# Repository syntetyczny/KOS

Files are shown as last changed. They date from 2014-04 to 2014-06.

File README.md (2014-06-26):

KOS
===

Another RepRap controller based on teensylu/printrboard and more. 

Project and all files attached are licensed by Creative Commons license CC BY-NC-ND 3.0 . If you want to comercially use project contact the author:
Paweł Janusz Dobrowolski
email: pawel.j.dobrowolski@gmail.com
company email: pjd@pjd-automatyka.pl

legal links:
http://creativecommons.org/licenses/by-nc-nd/3.0/
http://creativecommons.org/licenses/by-nc-nd/3.0/pl/legalcode
http://creativecommons.org/licenses/by-nc-nd/3.0/pl/

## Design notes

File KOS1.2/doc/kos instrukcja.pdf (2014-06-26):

## Instrukcja obsługi do kontrolera 4 osiowego dla drukarek 3D typu RepRap

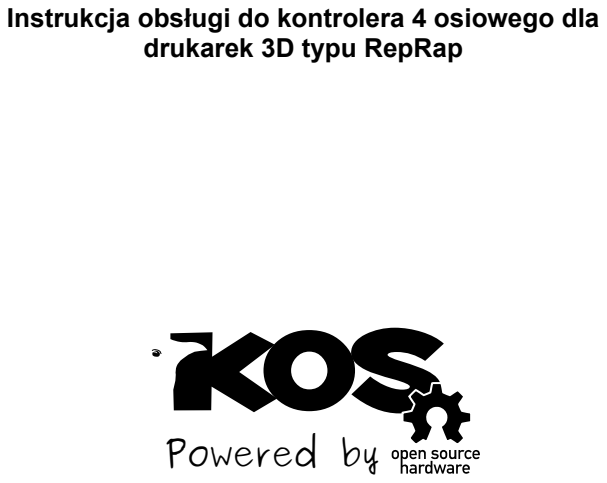
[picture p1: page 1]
Powered by

## Spis treści

## 1 Wstęp

KOS 1.2 jest elektroniką stworzoną z uwzględnieniem doświadczenia zebranego na budowaniu drukarek 3D Prusa. Wyposażono ją w złącza śrubowe, szeroko stosowane w elektronice przemysłowej, które eliminują błędy montażowe takie jak źle zaciśnięte wtyczki, czy też zbyt mała powierzchnia styku. Sterownik KOS 1.2 został dodatkowo wyposażony w czytelne złącza pod ekran LCD, czytnik karty SD oraz enkoder z guzikiem 47. Dzięki temu możemy bez problemu umieścić panel sterujący drukarką tam, gdzie nam się podoba. Na płytce umieszczono dodatkowo potencjometr do regulacji kontrastu wyświetlacza oraz rezystor regulujący intensywność podświetlenia, co zmniejsza poziom skomplikowania przy montażu dodatkowych peryferiów.

Jedną niezaprzeczalną zaletą elektroniki KOS jest możliwość stosowania naraz 3 różnych napięć. Oznacza to, że możemy silniki zasilić napięciem Vmot od 12-30V, grzałek napięciem Vhot od 12-30V i logiki napięciem P1 = 12V bądź zasilić logikę z portu USB 5. Taka ilość możliwości nie każdemu jest potrzebna, więc wprowadzono dodatkowo zworki pozwalające na przełączanie zasilania dla uproszczenia instalacji.

Elektronika KOS 1.2 jest wyposażona w procesor AT90USB1286/7 , który jest szeroko stosowanym kontrolerem 8 bitowym w drukarkach 3D typu RepRap. Jego zaletą jest natywna obsługa portu USB, pozwalająca na szybką wymianę danych i bezproblemową komunikację pomiędzy komputerem, a drukarką. Procesor ten jest stosowany w elektronikach takich jak Teensylu, Printrboard, SAV MKI, Sunbeam, Uniqueone i wiele innych. Jest to najpopularniejszy procesor z rodziny AVR w świecie druku 3D.

## 2 Schemat podłączeniowy

Poniżej przedstawiono schemat podłączenia podstawowych peryferiów drukarki 3D takich jak: grzałka, podgrzewany stół, silniki itd. Trzeba pamiętać o dobraniu odpowiednich kabli o odpowiednim przekroju.

- Silniki: 0.35mm²
- Grzałki: 1.5mm²
- Krańcówki, termistory, wyłącznik bezpieczeństwa E-Stop: 0.35mm²
- Zasilacze: 1.5mm²

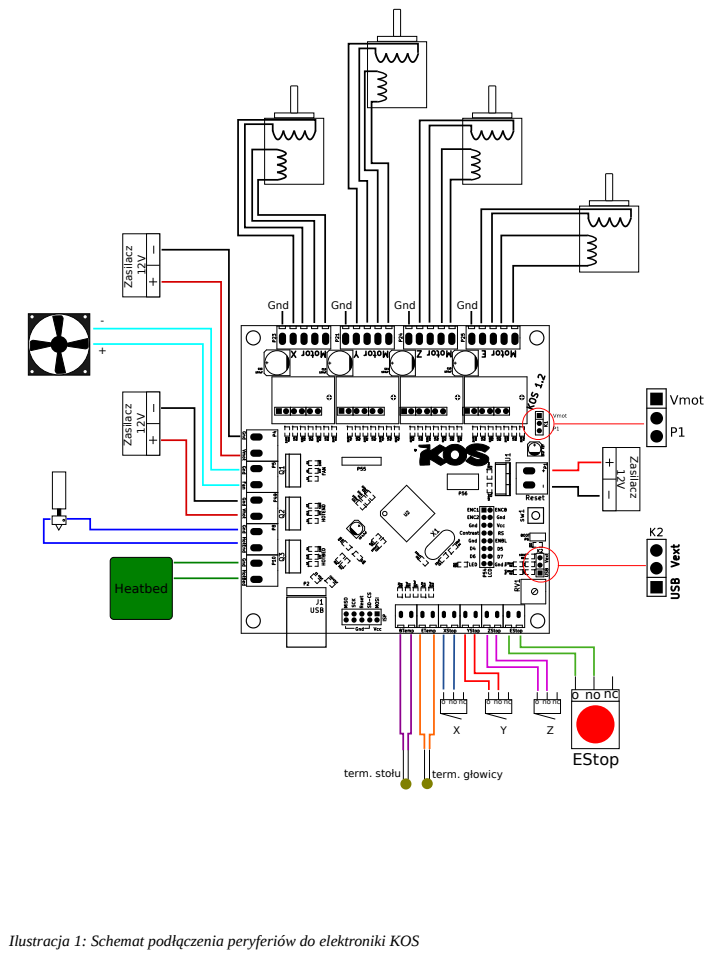
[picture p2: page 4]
Heatbed; term. stołu; term. głowicy; EStop; Zasilacz; Gnd

Ilustracja 1: Schemat podłączenia peryferiów do elektroniki KOS

### 2.1 Opis zworek odpowiadających za zasilanie

W elektronice KOS występuje możliwość podpięcia różnych rodzajów zasilania w zależności od aplikacji. W związku z tym, umieszczono 2 listwy kołkowe, które odpowiadają za przełączenie zasilania elektroniki z zasilania z portu USB na zasilanie ze złącza P1 – zasilania do 12V wyłącznie dla celów procesora i logiki, bądź z łącza Vmot – gdy zasilamy silniki napięciem 12V, możemy je wykorzystać również do zasilania procesora i logiki przełączając odpowiednią zworkę. W poniższej tabeli zaprezentowano możliwe konfiguracje.

lp. | Zworka | Opis
1 | | Brak wybranego zasilania dla elektroniki
2 | | Zasilanie elektroniki z portu USB bez względu na wybór źródła napięcia na zworce K1
3 | | Zasilanie ze źródła zewnętrznego Vmot wybranego na zworce K1
4 | | Zasilanie ze źródła zewnętrznego P1 wybranego na zworce K1

### 2.2 Opis zworek odpowiedzialnych za wybór kroków

Do każdego silnika krokowego są przypisane zworki odpowiadające za podział kroków na sterownikach silników krokowych opartych o układ scalony firmy Allegro A4988. Poniżej opisano możliwe konfiguracje.

lp. | Zworki | Opis
1 | | Tryb pełno krokowy (1)
2 | | Tryb półkrokowy (½)
3 | | Tryb ¼ kroku (¼)
4 | | Tryb 1/8 kroku (1/8)
5 | | Tryb 1/16 kroku (1/16)

## 3 Sterowniki i oprogramowanie dla systemu Windows

Elektronika KOS jest zaprojektowana tak aby była kompatybilna wstecznie z elektroniką teensylu, więc aby poprawnie działała z komputerem, wymagana jest instalacja sterowników. Jeżeli elektronika jest dostarczona z już wgranym programem Marlin, wystarczy zainstalować sterowniki ze strony projektu teensy 1.

W przeciwnym przypadku musimy stworzyć nową kompilację Marlin'a postępując zgodnie z instrukcją w dziale „Kompilacja Marlina” 5. Jednakże, zanim przejdziemy do tego, nasza elektronika wymaga bibliotek od oprogramowania Arduino, Teensyduino, oraz FLIP, które wcześniej musimy zainstalować:

- arduino ze strony autorów 2
- pakietu teensyduino 3
- programu FLIP for Windows 4

### 3.1 Instalacja pakietu Arduino

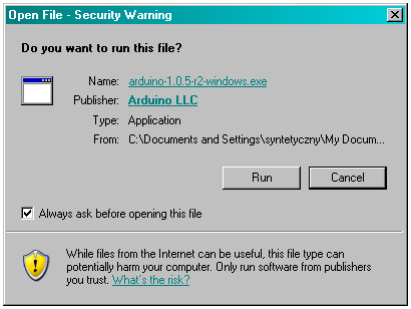
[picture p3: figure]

Ilustracja 2: Zezwolenie na uruchomienie pliku z niewiadomego źródła

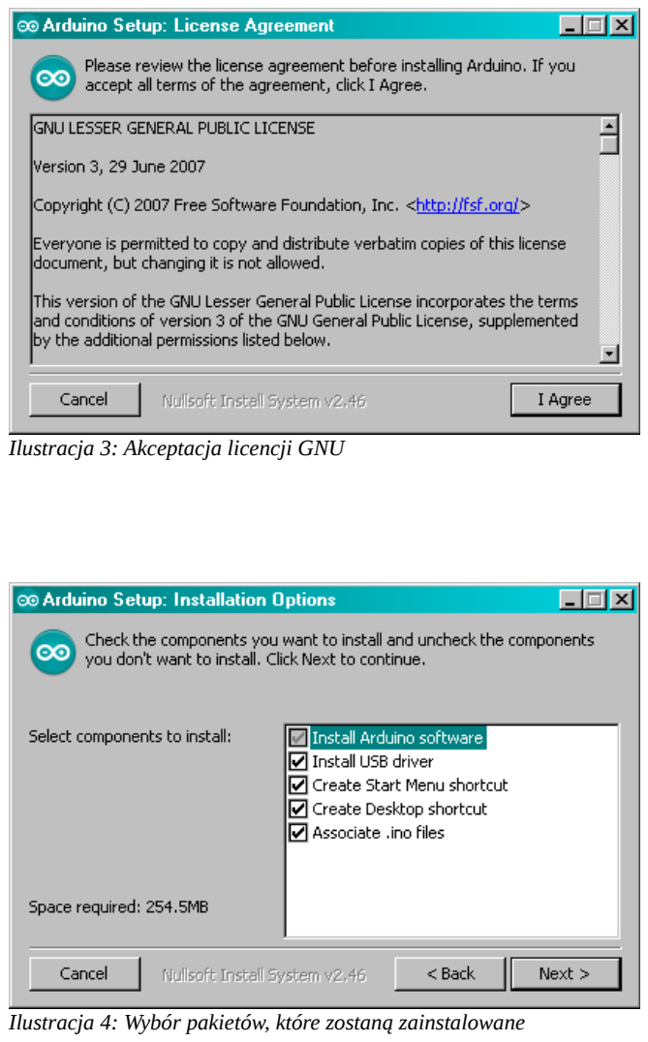
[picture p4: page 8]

Ilustracja 3: Akceptacja licencji GNU

Ilustracja 4: Wybór pakietów, które zostaną zainstalowane

Ilustracja 5: Wybór lokalizacji, gdzie zostanie zainstalowane Arduino

Ilustracja 6: Ostrzeżenie systemu Windows przed instalowaniem niezweryfikowanego oprogramowania

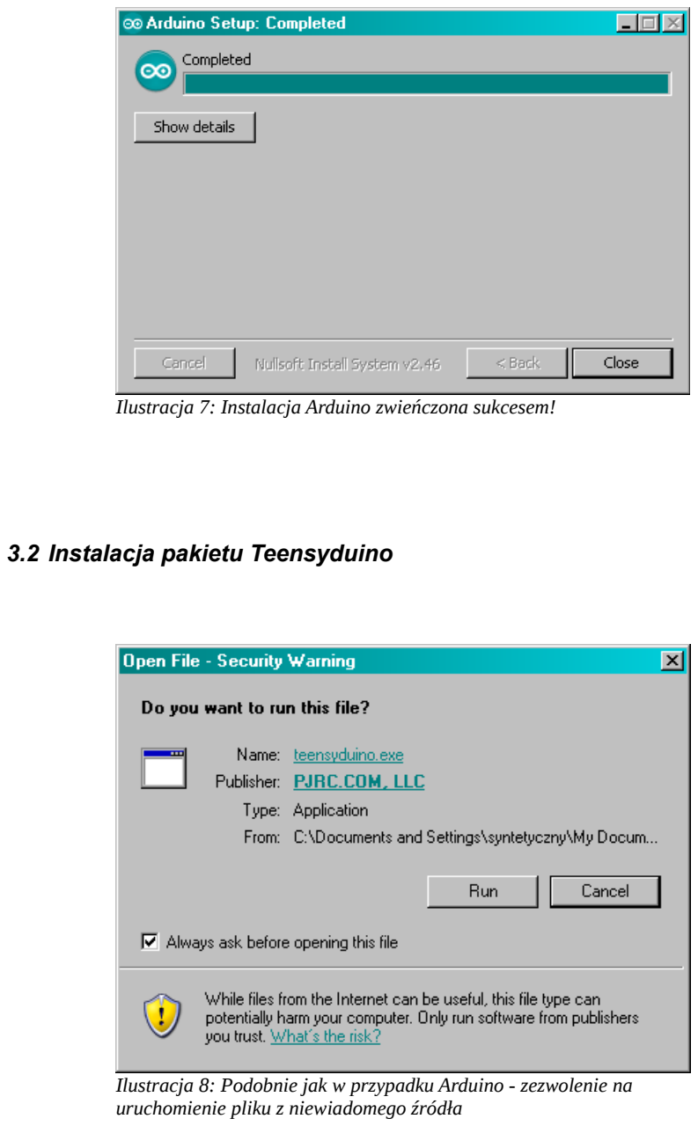
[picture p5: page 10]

### 3.2 Instalacja pakietu Teensyduino

Ilustracja 8: Podobnie jak w przypadku Arduino - zezwolenie na uruchomienie pliku z niewiadomego źródła

Ilustracja 7: Instalacja Arduino zwieńczona sukcesem!

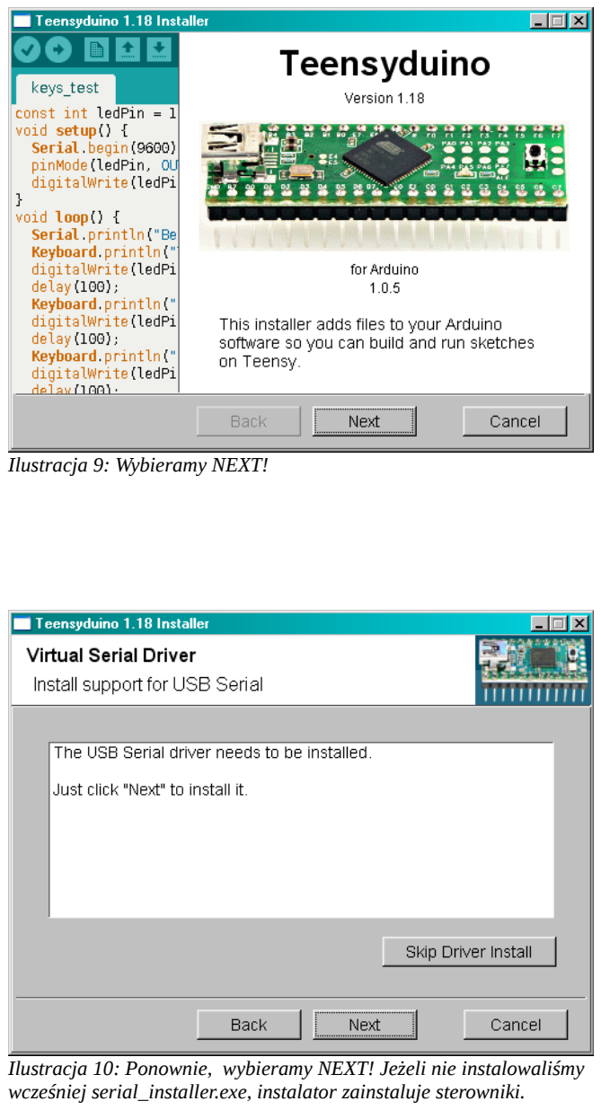
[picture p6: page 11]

Ilustracja 9: Wybieramy NEXT!

Ilustracja 10: Ponownie, wybieramy NEXT! Jeżeli nie instalowaliśmy wcześniej serial_installer.exe, instalator zainstaluje sterowniki.

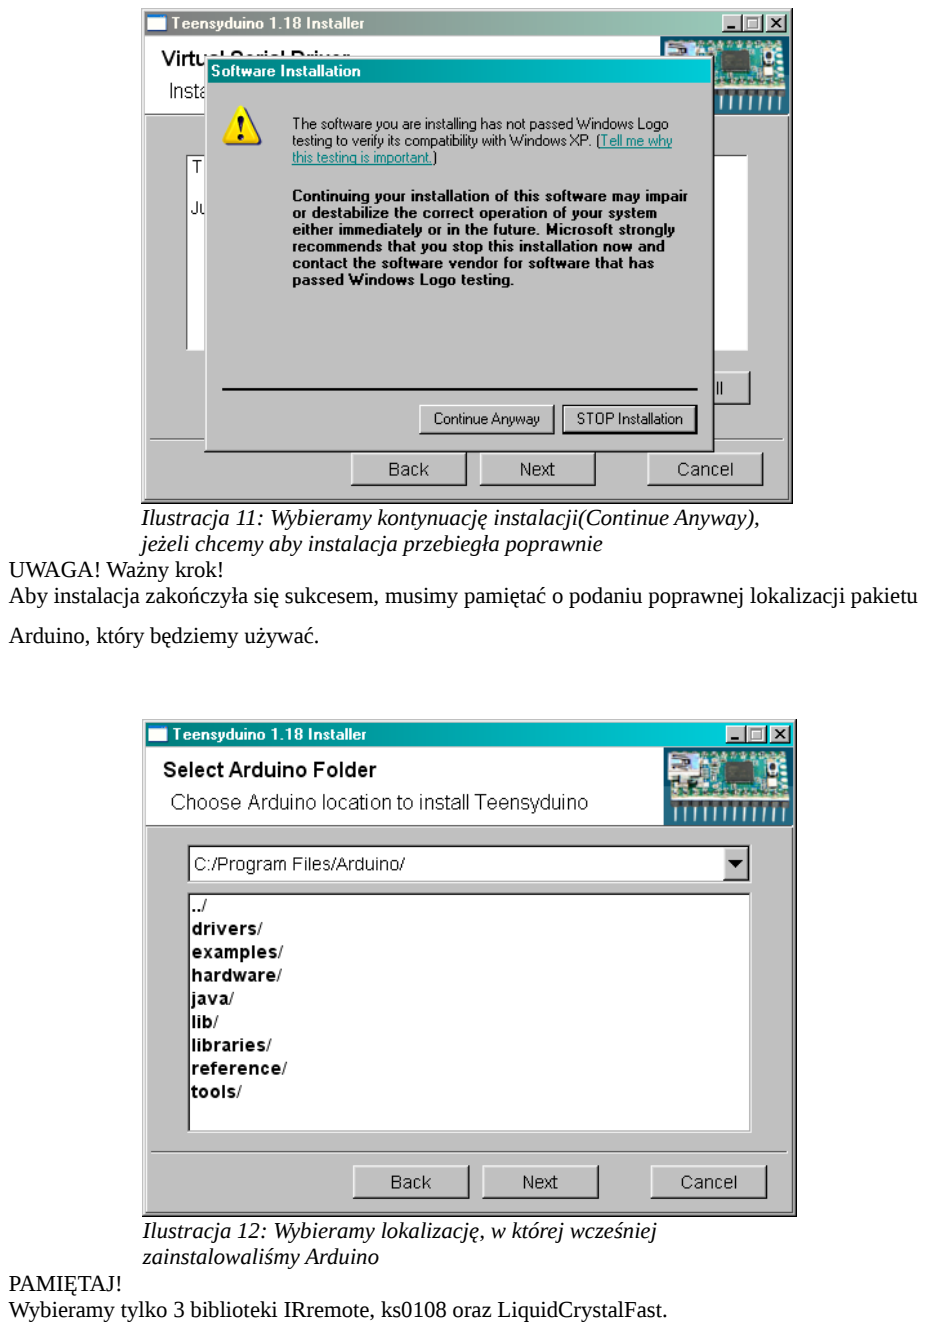
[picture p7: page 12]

UWAGA! Ważny krok!
Aby instalacja zakończyła się sukcesem, musimy pamiętać o podaniu poprawnej lokalizacji pakietu Arduino, który będziemy używać.

PAMIĘTAJ!
Wybieramy tylko 3 biblioteki IRremote, ks0108 oraz LiquidCrystalFast.

Ilustracja 11: Wybieramy kontynuację instalacji(Continue Anyway), jeżeli chcemy aby instalacja przebiegła poprawnie

Ilustracja 12: Wybieramy lokalizację, w której wcześniej zainstalowaliśmy Arduino

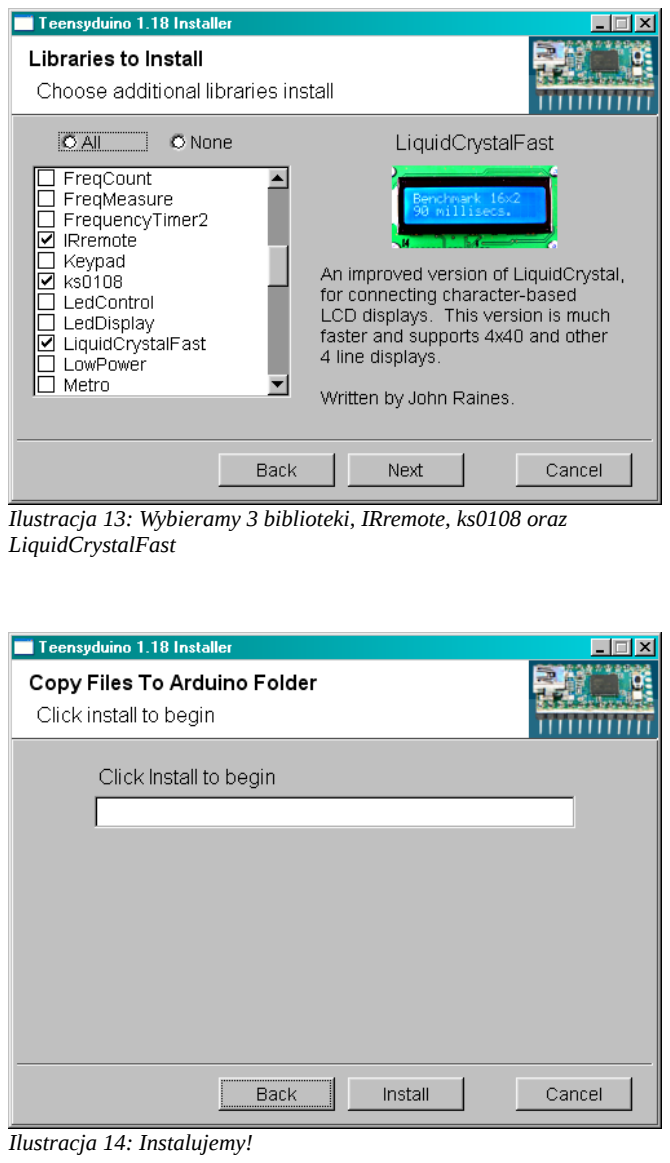
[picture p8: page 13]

Ilustracja 13: Wybieramy 3 biblioteki, IRremote, ks0108 oraz LiquidCrystalFast

Ilustracja 14: Instalujemy!

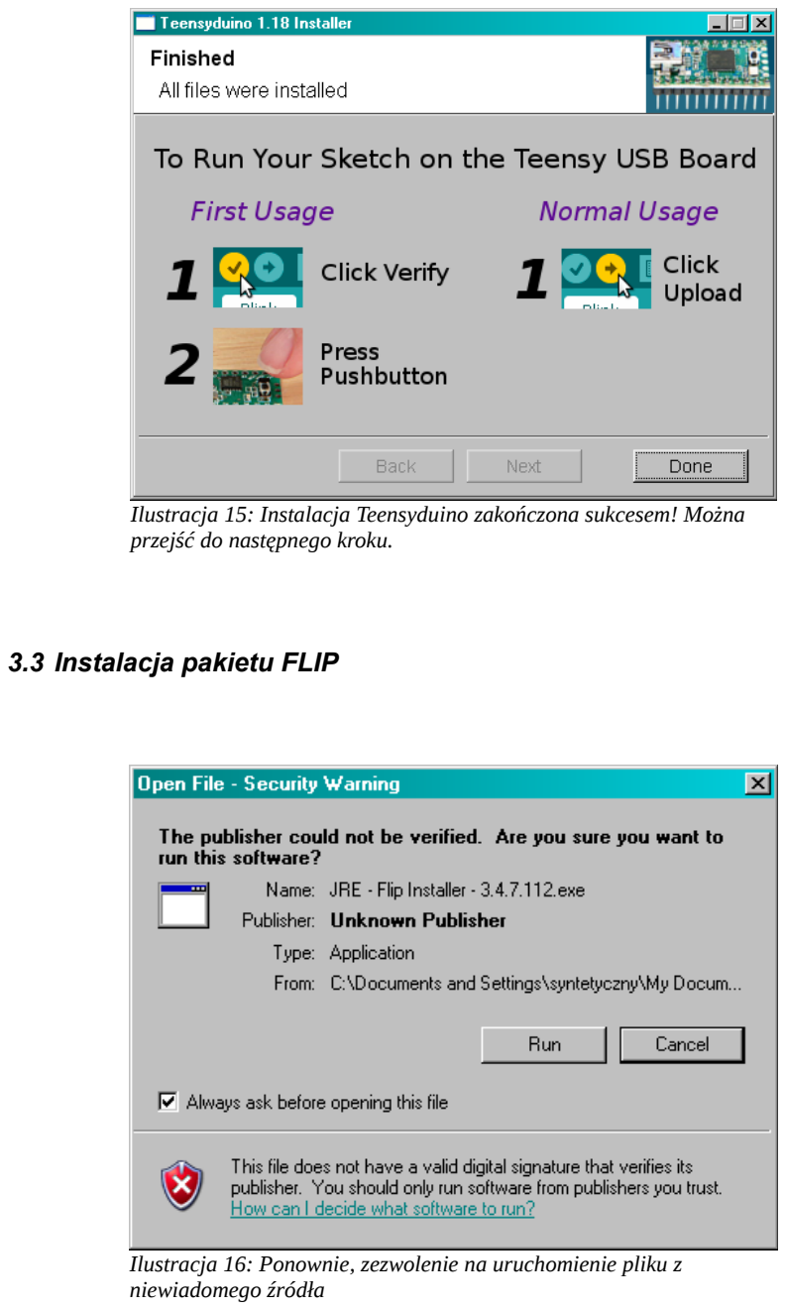
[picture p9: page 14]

### 3.3 Instalacja pakietu FLIP

Ilustracja 15: Instalacja Teensyduino zakończona sukcesem! Można przejść do następnego kroku.

Ilustracja 16: Ponownie, zezwolenie na uruchomienie pliku z niewiadomego źródła

Ilustracja 17: W przypadku braku zainstalowanego pakietu Javy musimy ją doinstalować

Ilustracja 18: Wybieramy standardową instalację i akceptujemy. Możemy przejść do następnego kroku.

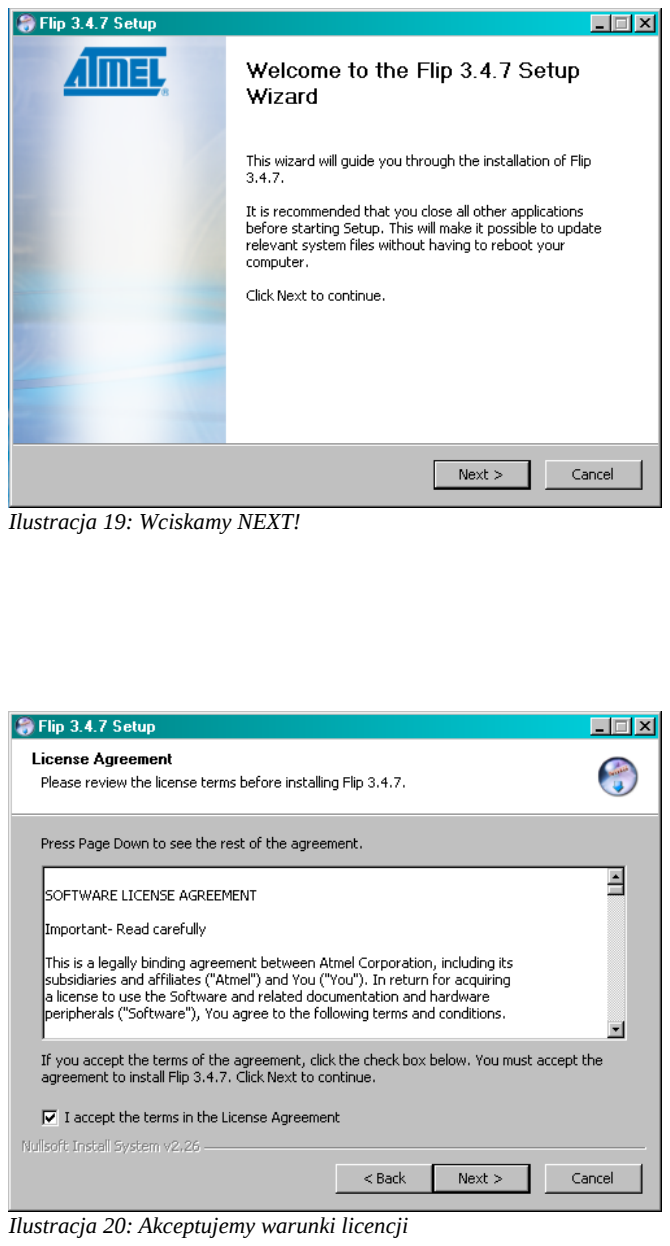
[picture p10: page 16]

Ilustracja 19: Wciskamy NEXT!

Ilustracja 20: Akceptujemy warunki licencji

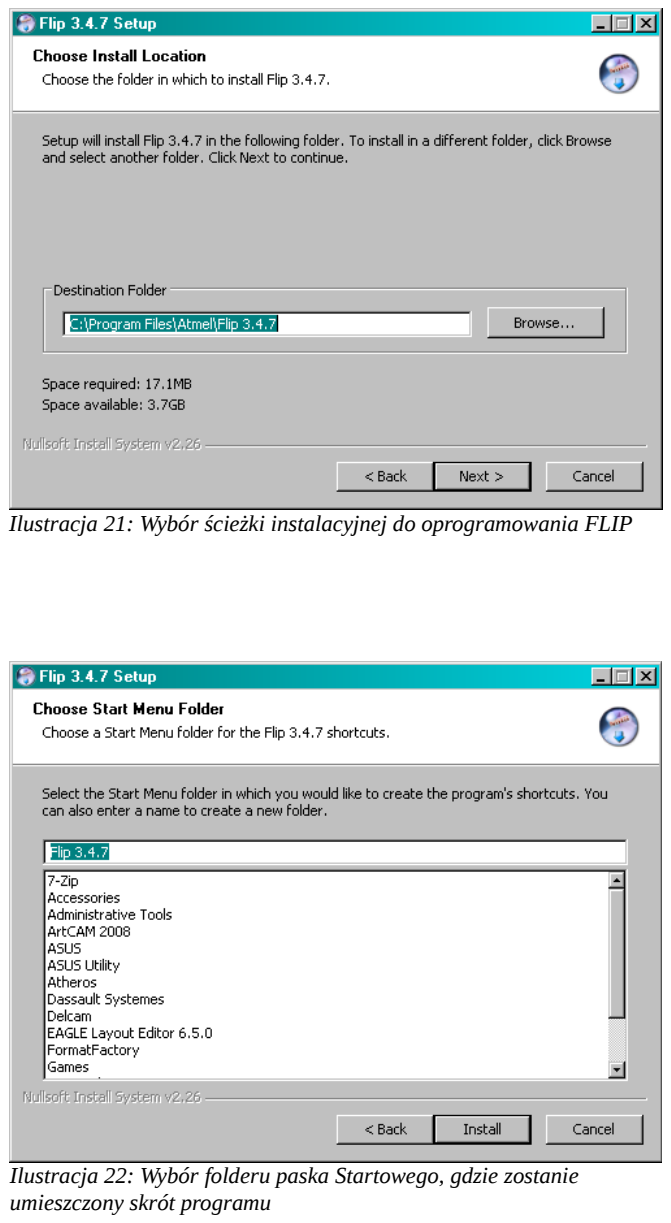
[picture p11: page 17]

Ilustracja 21: Wybór ścieżki instalacyjnej do oprogramowania FLIP

Ilustracja 22: Wybór folderu paska Startowego, gdzie zostanie umieszczony skrót programu

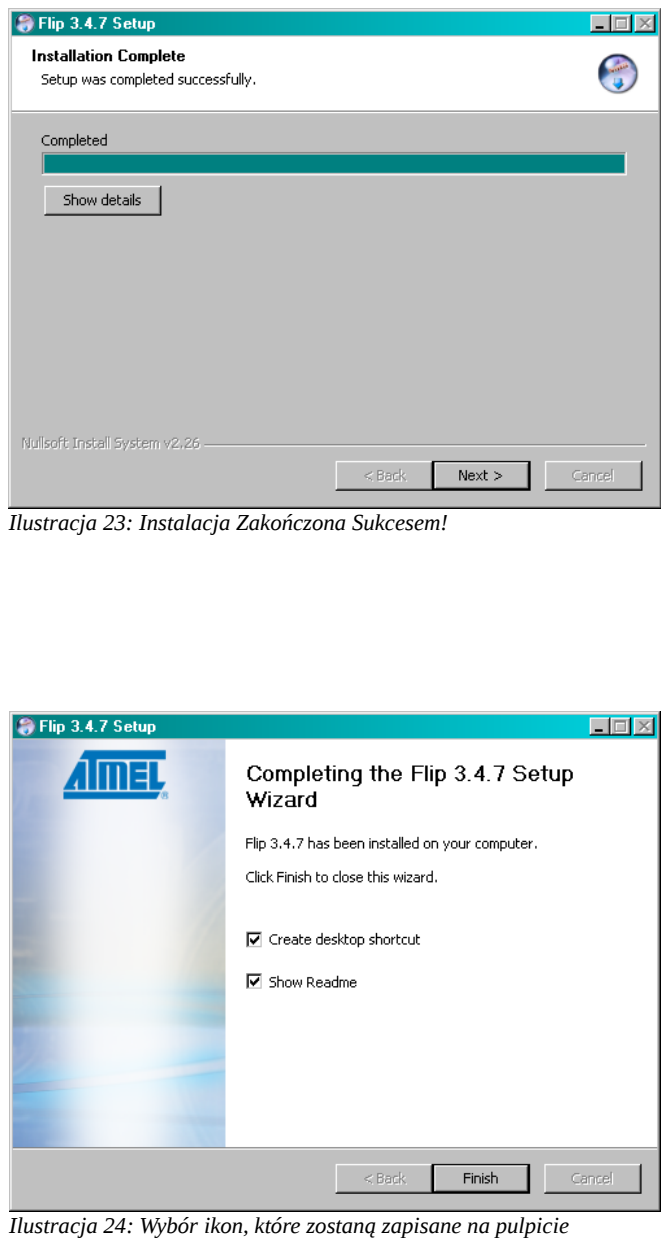
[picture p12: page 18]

Ilustracja 23: Instalacja Zakończona Sukcesem!

Ilustracja 24: Wybór ikon, które zostaną zapisane na pulpicie

## 4 Sterowniki i oprogramowanie dla systemów Linux Ubuntu

Tak samo jak w przypadku sterowników dla systemu Windows, zaczynamy od ściągnięcia pakietu Arduino ze strony producenta 2 . I rozpakowaniu w dowolnej lokalizacji. Następnie przy pomocy terminala, doinstalowujemy potrzebne pakiety:

sudo apt-get install gcc-avr avr-libc

sudo apt-get install openjdk-6-jre

Następnie, dodajemy prawa wykonywania dla programu Arduino. W tym celu musimy przejść do folderu z rozpakowanym Arduino i przy użyciu prawego klawisza myszki wejść we Właściwości i w zakładce Uprawnienia zaznaczyć Zezwolenie na wykonanie pliku jako programu .

Następnie, pobieramy teensyduino ze strony autorów w wersji zgodnej z naszym systemem(32 / 64 bity) i zapisujemy w dogodnej dla nas lokalizacji. Aby móc uruchomić program, otwieramy terminal (ctrl + alt + t) i przechodzimy do miejsca, gdzie znajduje się plik:

cd /home/nazwa_użytkownika/Lokalizacja/Pliku

Następnie za pomocą komendy chmod nadajemy prawa wykonywania pliku teensyduino.32bit

chmod 755 teensyduino.32bit

A następnie uruchamiamy instalator przy pomocy komendy ./teensyduino.32bit i postępujemy zgodnie z poleceniami instalatora:

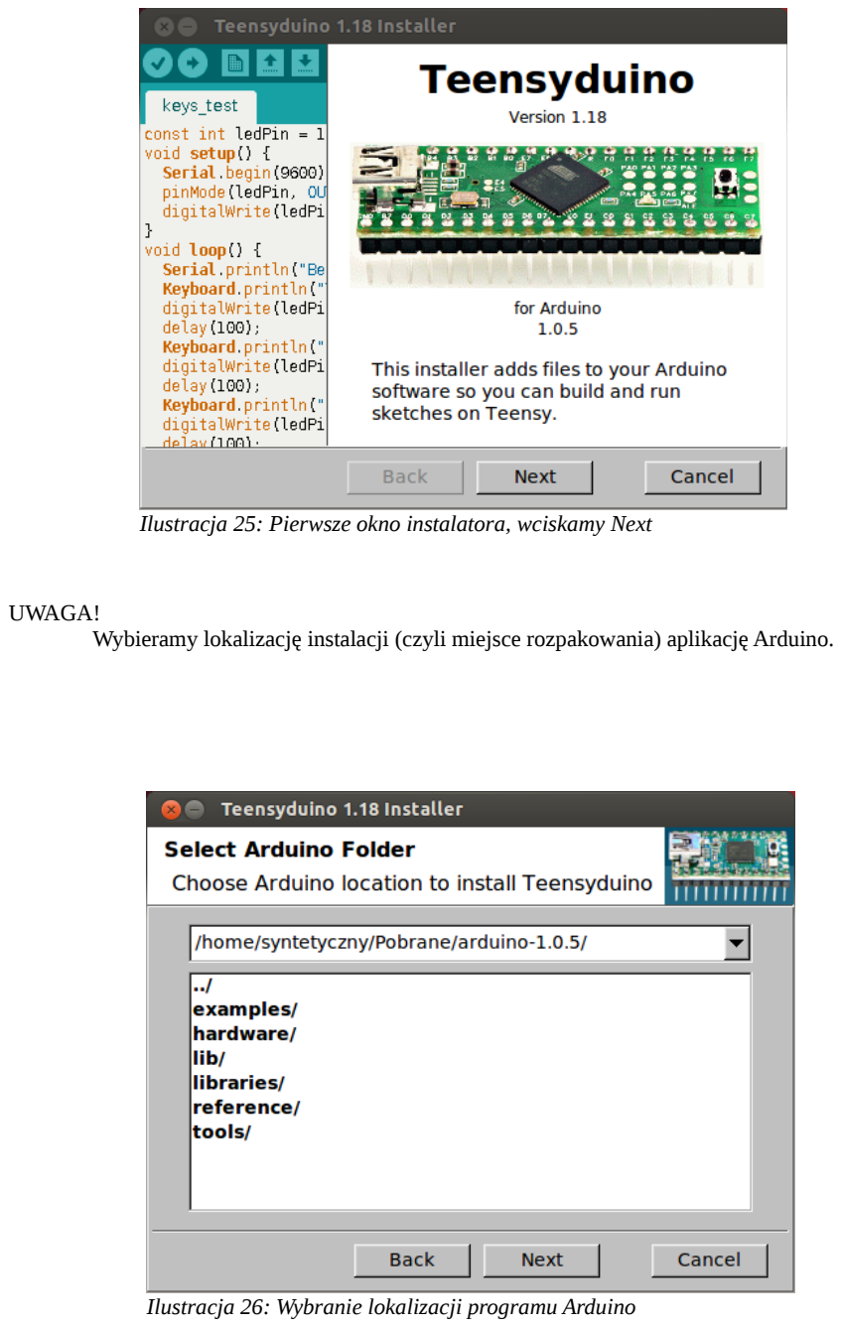
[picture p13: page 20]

UWAGA!
Wybieramy lokalizację instalacji (czyli miejsce rozpakowania) aplikację Arduino.

Ilustracja 25: Pierwsze okno instalatora, wciskamy Next

Ilustracja 26: Wybranie lokalizacji programu Arduino

Ważny krok instalacji!
Teraz wybieramy biblioteki, potrzebne do poprawnego działania Arduino. Pamiętaj, aby wybrać IRremote, js0108, LiquidCrystalFast.

Ilustracja 28: Wystarczy wcisnąć Install.

Ilustracja 27: Wybieramy potrzebne biblioteki i wciskamy Next

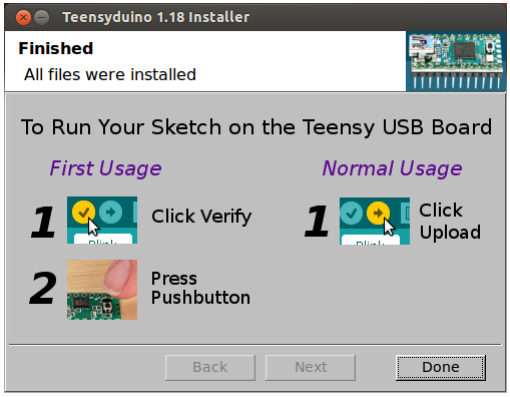
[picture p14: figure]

Kolejnym krokiem przy instalacji programów jest zainstalowanie odpowiednika programu Flip do programowania procesorów serii AT90USB. Wciskając na klawiaturze Ctr +Alt + T wywołujemy terminal, w który wklejamy za pomocą prawego klawisza myszki komendę:

sudo apt-get install dfu-programmer

Instalator sam pobierze niezbędną aplikację z internetu i zainstaluje program na dysku naszego komputera. I w ten oto sposób, zakończyliśmy instalację niezbędnych sterowników/bibliotek służących do kompilacji programu Marlin dla sterownika KOS.

Ilustracja 29: Wciskamy Done kończąc tym samym instalację.

## 5 Kompilacja i wgranie programu Marlin do sterownika KOS

W tym dziale zostanie ogólnie opisana kompilacja programu Marlin. Jest to spowodowane tym, że ustawienia są różne dla różnych konfiguracji sprzętowych. Dodatkowo dział ten zostanie podzielony na 2 sekcje Windows i Ubuntu, ze względu na pewne różnice podczas wgrywania pliku binarnego hex do pamięci mikroprocesora.

### 5.1 Edycja Marlina

Pobrane wcześniej pliki ze strony autorów Marlina 5 rozpakowujemy do katalogu, w którym będziemy edytować program. Następnie przy pomocy dowolnego narzędzia edytorskiego (np. Notepad++), otwieramy plik Configuration.h i przychodzimy do linijki #define BAUDRATE 250000 gdzie zamiast 250000 wpisujemy 115000.

Następnie przechodzimy do linijki #define MOTHERBOARD 7 i zmieniamy 7 na 8. Tym samym zmieniając domyślną konfigurację dla płyty sterownika drukarki ULTIMAKERa, na płytkę teensylu, z którą nasz sterownik jest kompatybilny (ze względu na użycie tego samego procesora).

Kolejnym krokiem będzie wybór termistorów jakie używamy w naszej konfiguracji. Standardowo, w większości głowic stosuje się termistory wysokotemperaturowe firmy EPCOS. Przejdźmy zatem do linijki, która zaczyna się tak:

#define TEMP_SENSOR_0 -1

#define TEMP_SENSOR_1 -1

#define TEMP_SENSOR_2 0

#define TEMP_SENSOR_BED 0

w każdym kolejnym wierszu mamy definicję użytego termistora dla 3 głowic, oraz dla grzanego stołu. Wartości jakie nas interesują to 1 dla TEMP_SENSOR_0 oraz jeżeli używamy podgrzewanego stołu TEMP_SENSOR_BED.

#define TEMP_SENSOR_0 1

#define TEMP_SENSOR_1 0

#define TEMP_SENSOR_2 0

#define TEMP_SENSOR_BED 1

W ten sposób, zdefiniowaliśmy termistory, używane w naszych drukarkach. Kolejnymi parametrami, którymi użytkownik powinien się zainteresować, to konfiguracja silników, a dokładniej kroki na mm oraz kierunek obrotu silników. Są to parametry, które mają znaczenie już po uruchomieniu drukarki, ale warto o nich wspomnieć już teraz.

Kierunek ruchu silników jest zdefiniowany w linijce:

#define INVERT_X_DIR true

#define INVERT_Y_DIR false

#define INVERT_Z_DIR true

#define INVERT_E0_DIR false

#define INVERT_E1_DIR false

#define INVERT_E2_DIR false

Każdy wiersz opisuje kolejno ruch w osiach X,Y,Z oraz kierunek obracania się ekstrudera E0,E1,E2. W większości przypadków mamy do czynienia z 1 ekstruderem E0.

Wartości true oraz false, odpowiadają za kierunek obrotu silnika. Jeżeli w obecnej konfiguracji, silniki kręcą się w złym kierunku, zmieniamy true na false bądź odwrotnie w zależności, co było w danej osi zdefiniowane. Aby sprawdzić, czy ekstruder kręci się w poprawnym kierunku, wystarczy wpisać w okienku komend M302 i wciskając extrude sprawdzić czy w poprawnym kierunku kręci się silnik wytłaczarki.

Następnie przejdziemy do wiersza odpowiadającego za przypisanie ilości kroków na mm.

#define DEFAULT_AXIS_STEPS_PER_UNIT {78.7402,78.7402,200.0*8/3,760*1.1}

Powyższa linijka odpowiada za przypisanie ilości kroków na 1 mm w osiach {X , Y, Z, E}, których wartość można w łatwy sposób wyliczyć, korzystając z kalkulatora Josefa Prusy 6 .

Mając tak przygotowany plik, możemy go zapisać i przejść do programu Arduino.

### 5.2 Kompilacja Marlina

Otwarcie projektu Marlin wymaga od nas wybrania Plik → Otwórz... i wybranie pliku Marlin.ino. Po czym otworzy nam się projekt Marlin jak na ilustracji poniżej 30.

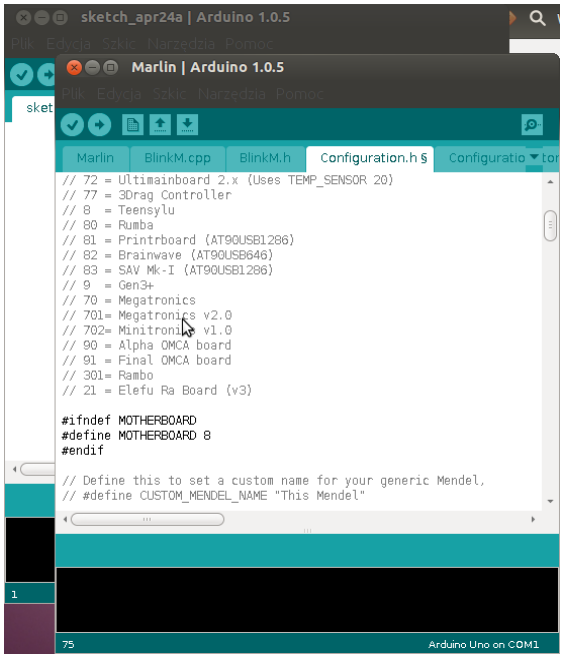
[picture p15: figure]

Ilustracja 30: Okno Arduino

Wszystkie ważne informacje w projekcie na które mamy wpływ, zostały zawarte w pliku Configuration.h i dotyczą podstawowej konfiguracji maszyny. W zakładce Narzędzia → Board należy wybrać Teensy2.0++ i przejść do kompilacji projektu poprzez kliknięcie lewym klawiszem myszy w ptaszka znajdującego się w lewym górnym rogu aplikacji jak na ilustracji poniżej 31.

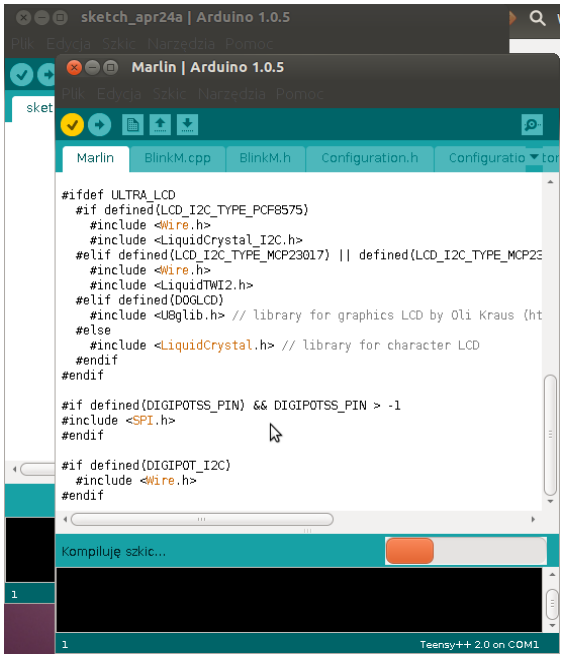
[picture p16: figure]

Następnie po ukończeniu kompilacji powinno pojawić się okno z wyborem programu pod nazwą Marlin.cpp.hex 32.

Ilustracja 31: Rozpoczęcie kompilacji Marlina

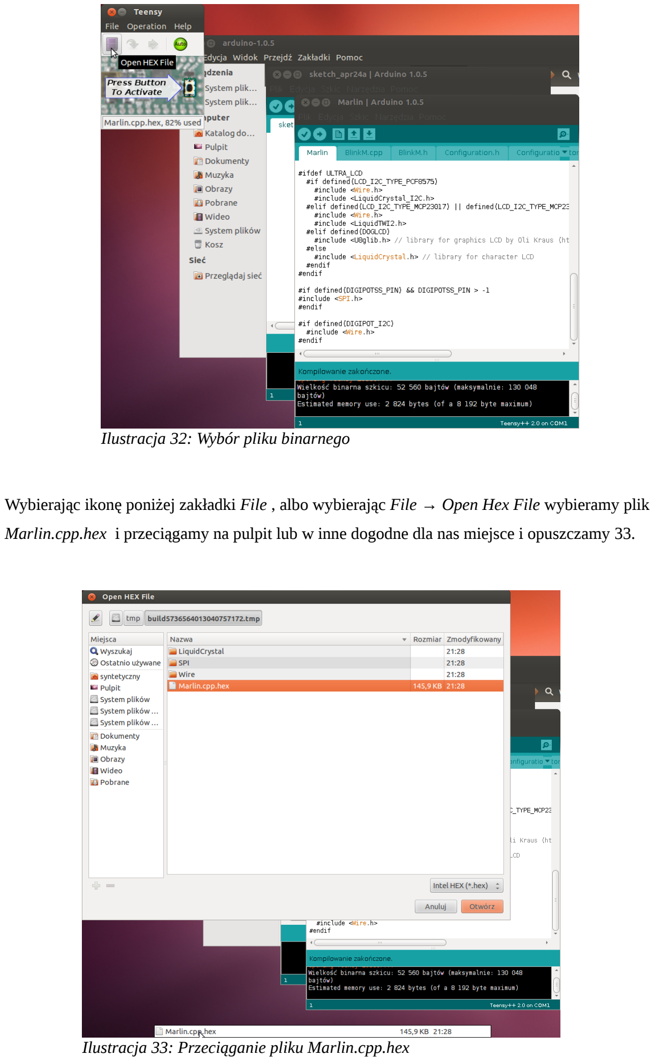
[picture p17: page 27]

Wybierając ikonę poniżej zakładki File , albo wybierając File → Open Hex File wybieramy plik Marlin.cpp.hex i przeciągamy na pulpit lub w inne dogodne dla nas miejsce i opuszczamy 33.

Ilustracja 32: Wybór pliku binarnego

Ilustracja 33: Przeciąganie pliku Marlin.cpp.hex

### 5.3 Wgranie Marlin.cpp.hex do pamięci sterownika KOS na systemie

Windows

Wgranie programu do sterownika odbywa się za pośrednictwem oprogramowania Flip. Zanim jednak przejdziemy do programowania podłączamy sterownik KOS do komputera, wyciągamy zworkę BOOT i wciskamy guzik reset przez 5sec w celu wprowadzenia sterownika w stan programowania. Jeżeli robimy to pierwszy raz, system poinformuje nas o nowym sprzęcie. Instalacja sterowników przebiega tak samo jak w przypadku innych urządzeń typu USB, z tym wyjątkiem, że podczas instalacji wskazujemy konkretny folder ze sterownikiem w folderze Atmel/Flip 3.4.7/usb.

Po instalacji zakończonej sukcesem przechodzimy do programu Flip.

Program wymaga wskazania procesora, który będziemy programować, odbywa się to za pomocą pierwszej ikony z lewej.

UWAGA!

Ilustracja 34: Główne okno programu Flip

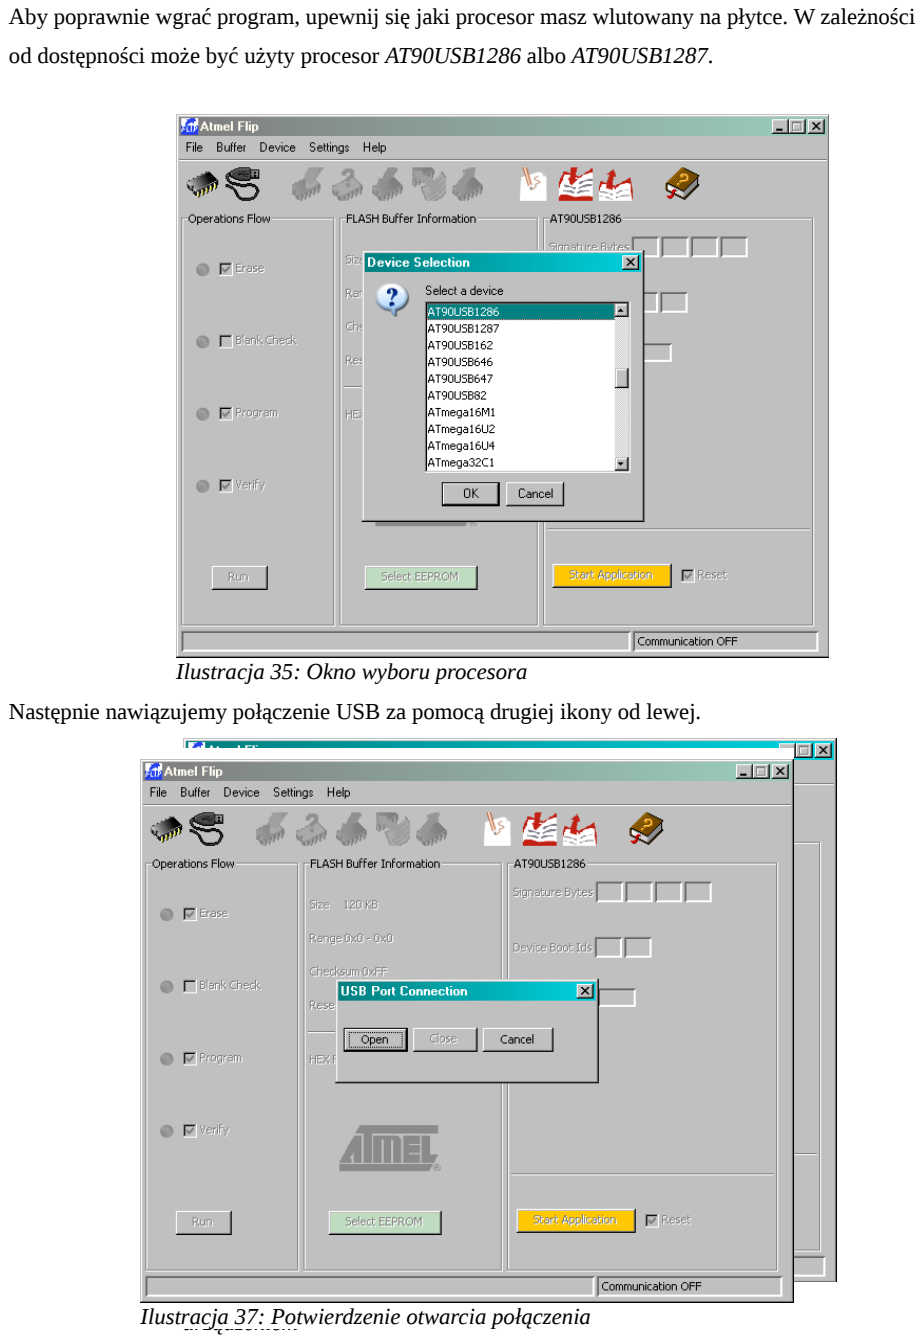
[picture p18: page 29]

Aby poprawnie wgrać program, upewnij się jaki procesor masz wlutowany na płytce. W zależności od dostępności może być użyty procesor AT90USB1286 albo AT90USB1287.

Następnie nawiązujemy połączenie USB za pomocą drugiej ikony od lewej.

Ilustracja 35: Okno wyboru procesora

Ilustracja 36: Wybór połączenia USB ze wcześniej zdefiniowanym Ilustracja urządzeniem 37: Potwierdzenie otwarcia połączenia

Jeżeli urządzenie jest poprawnie zainstalowane program powinien nawiązać połączenie. Następnie powinniśmy wskazać kolejność operacji jakie chcemy wykonać. W tym przypadku wybieramy Erase i Program w oknie Operations Flow .

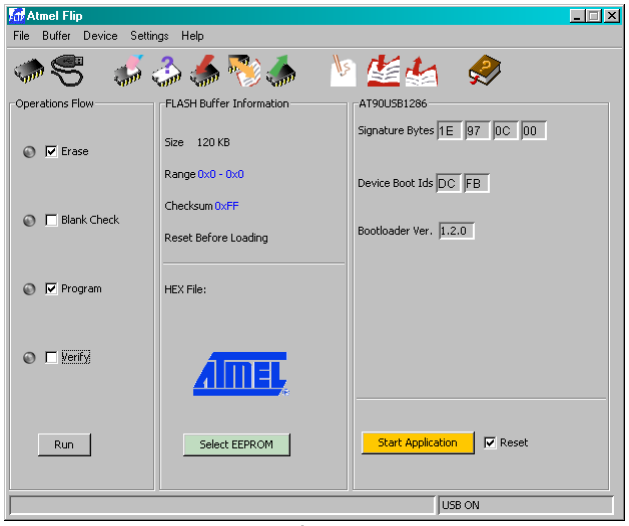
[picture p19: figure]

Następnie wybieramy program jaki chcemy załadować do procesora.

Ilustracja 38: Ustawienie kolejności operacji

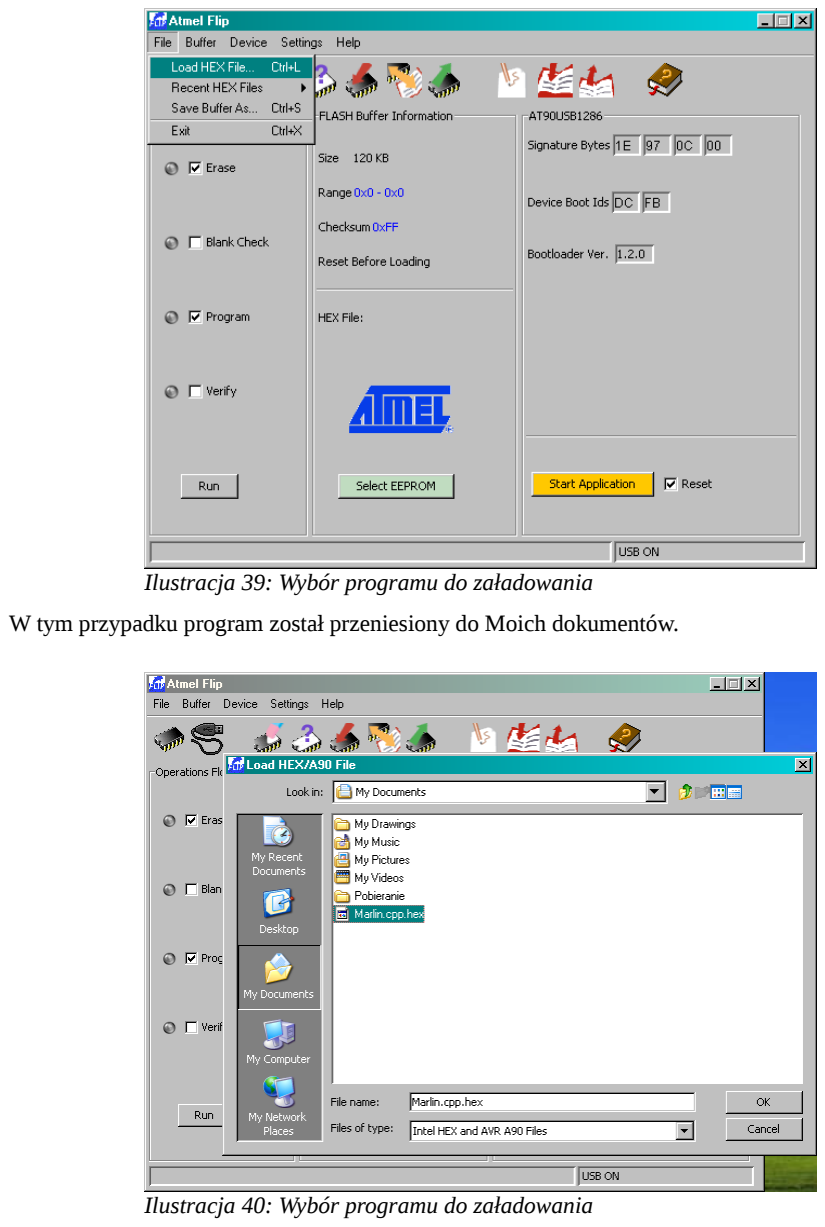
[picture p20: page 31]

W tym przypadku program został przeniesiony do Moich dokumentów.

Ilustracja 39: Wybór programu do załadowania

Ilustracja 40: Wybór programu do załadowania

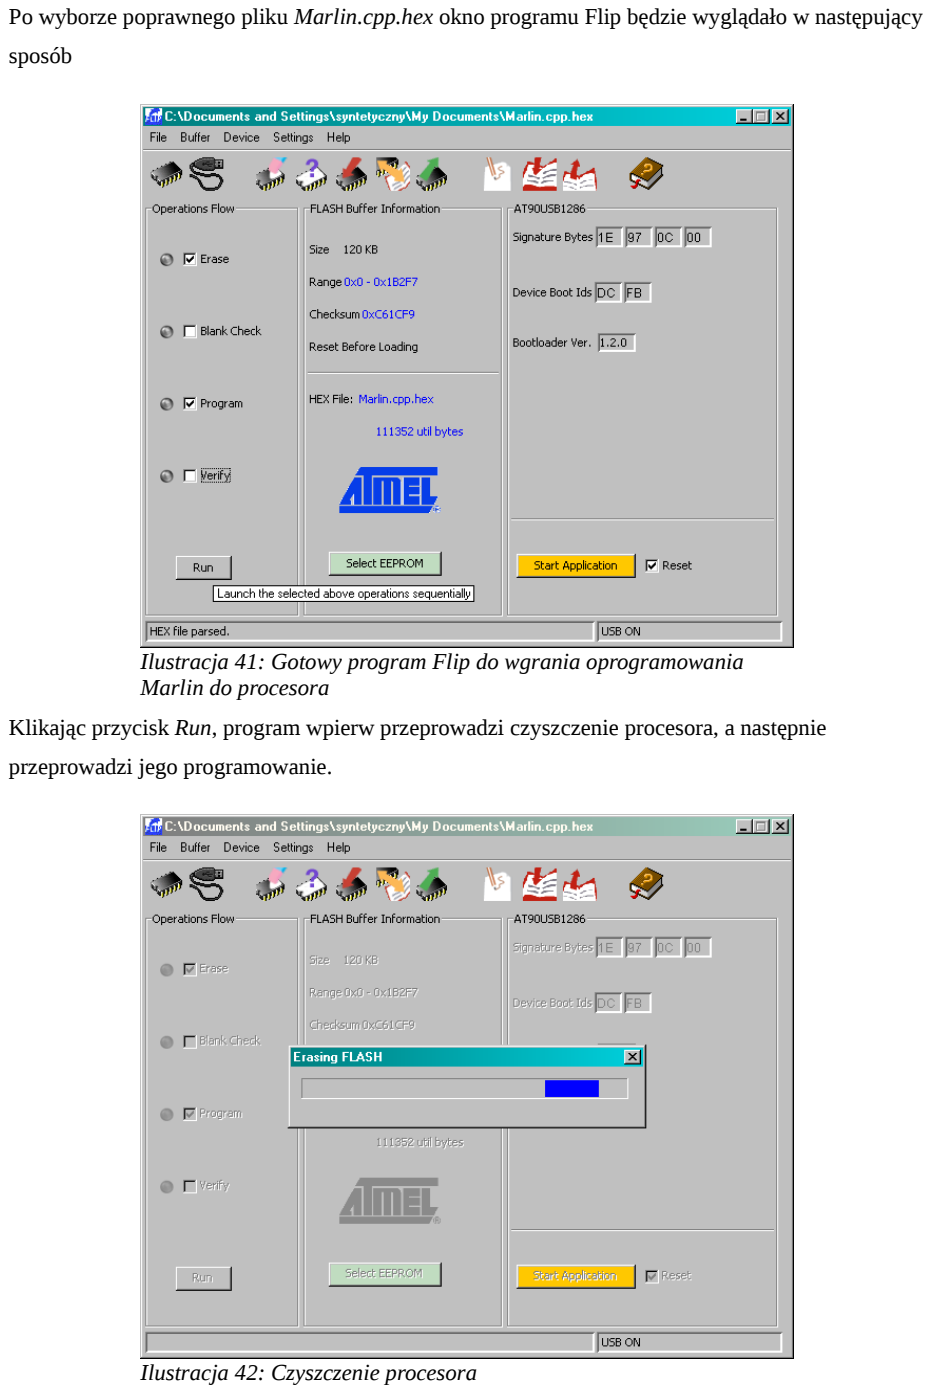
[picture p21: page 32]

Po wyborze poprawnego pliku Marlin.cpp.hex okno programu Flip będzie wyglądało w następujący sposób

Klikając przycisk Run, program wpierw przeprowadzi czyszczenie procesora, a następnie przeprowadzi jego programowanie.

Ilustracja 41: Gotowy program Flip do wgrania oprogramowania Marlin do procesora

Ilustracja 42: Czyszczenie procesora

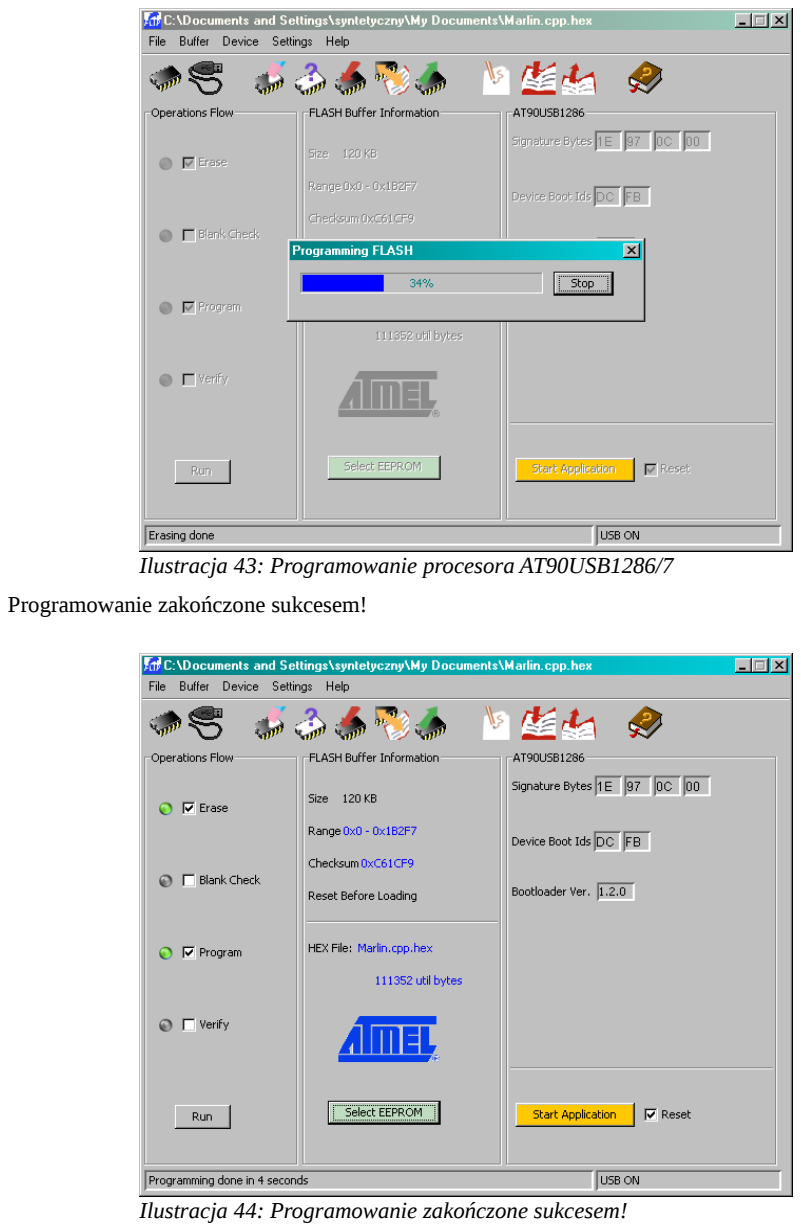
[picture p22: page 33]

Programowanie zakończone sukcesem!

Ilustracja 43: Programowanie procesora AT90USB1286/7

Ilustracja 44: Programowanie zakończone sukcesem!

Po ponownym założeniu zworki BOOT i jednokrotnym wciśnięciu guzika Reset sterownik powinien pojawić się jako port wirtualny. Tak zaprogramowany sterownik nadaje się już do używania z drukarką.

### 5.4 Wgranie Marlin.cpp.hex do pamięci sterownika KOS na systemie

Linux

W celu zaprogramowania sterownika KOS przenosimy wpierw przygotowany plik Marlin.cpp.hex 33 do folderu głównego w systemie /home/nazwa_użytkownika/. Następnie przywołując terminal za pomocą skrótu Ctrl + Alt + T i sprawdzamy czy plik jest w folderze głównym za pomocą komendy dir -l Marlin.cpp.hex .

Mając pewność, że jesteśmy we właściwym katalogu, podłączamy sterownik KOS do komputera, wyciągamy zworkę BOOT i wciskamy guzik reset przez 5 sekund w celu wprowadzenia sterownika w stan programowania. Korzystając z komendy lsusb sprawdzamy czy sterownik wszedł w stan programowania.

Następnie, używając wcześniej zainstalowanego dfu-programmer czyścimy pamięć , a następnie wgrywamy program do pamięci procesora.

Ilustracja 45: Sprawdzenie czy procesor jest w stanie programowania

UWAGA!
Aby poprawnie wgrać program, upewnij się jaki procesor masz wlutowany na płytce. W zależności od dostępności może być użyty procesor AT90USB1286 albo AT90USB1287.

sudo dfu-programmer at90usb1286 erase

sudo dfu-programmer at90usb1286 flash Marlin.cpp.hex

Poprawnie przeprowadzone programowanie powinno się skończyć jak na niżej przedstawionej ilustracji

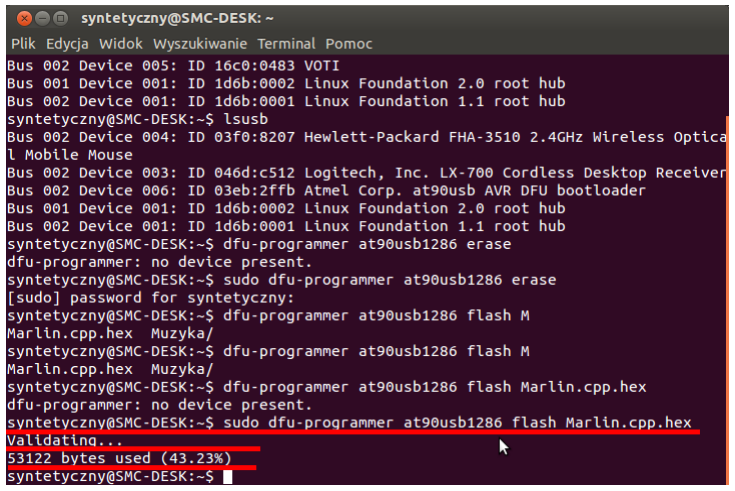
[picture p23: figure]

Po ponownym założeniu zworki BOOT i jednokrotnym wciśnięciu guzika Reset sterownik powinien pojawić się w jako VOTI po wpisaniu komendy lsusb. Tak zaprogramowany sterownik nadaje się już do używania z drukarką.

Ilustracja 46: Programowanie zakończone sukcesem

## 6 Źródła oraz dodatkowe konfiguracje dla sterownika KOS

Oprócz Marlina można również używać oprogramowania Repetier. W tym celu zostały opracowane repozytoria github z forkami tego oprogramowania, które wymagają jedynie kompilacji z interesującą nas mechaniczną konfiguracją. Aby je pobrać wystarczy udać się pod adresy:

https://github.com/syntetyczny/Marlin/tree/Marlin_KOS

https://github.com/syntetyczny/Repetier-Firmware

Są tam już wstępnie skonfigurowane programy dla elektroniki KOS. Konfiguracje te przewidują podłączenie karty SD, enkodera oraz Ekranu LCD zgodnie ze schematem przedstawionym poniżej.

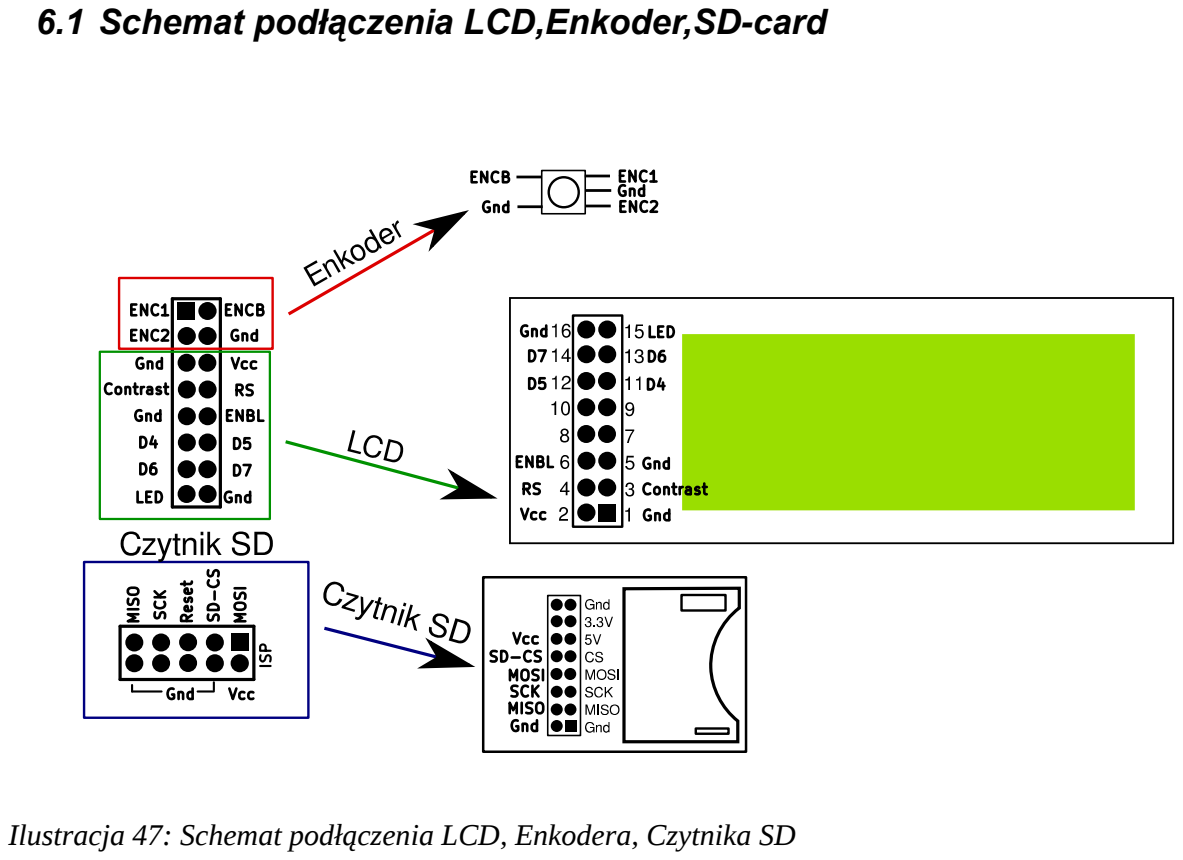
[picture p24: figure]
6.1 Schemat podłączenia LCD,Enkoder,SD-card

Ilustracja 47: Schemat podłączenia LCD, Enkodera, Czytnika SD

## 7 Bilbiografia

1. serial_install.exe z dnia 10.02.2014, www.pjrc.com/teensy/serial_install.exe
2. Arduino installer z dnia 23.04.2014, http://arduino.cc/en/Main/Software
3. Teensyduino z dnia 23.04.2014, http://www.pjrc.com/teensy/td_download.html
4. Flip for Windows z dnia 23.04.2014, http://www.atmel.com/tools/flip.aspx
5. Marlin z dnia 30.04.2014, https://github.com/ErikZalm/Marlin
6. Kalkulator Josefa Prusa z dnia 30.04.2014, http://calculator.josefprusa.cz/

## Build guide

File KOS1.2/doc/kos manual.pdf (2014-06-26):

Manual for 4 axis controller for RepRap 3D printer.

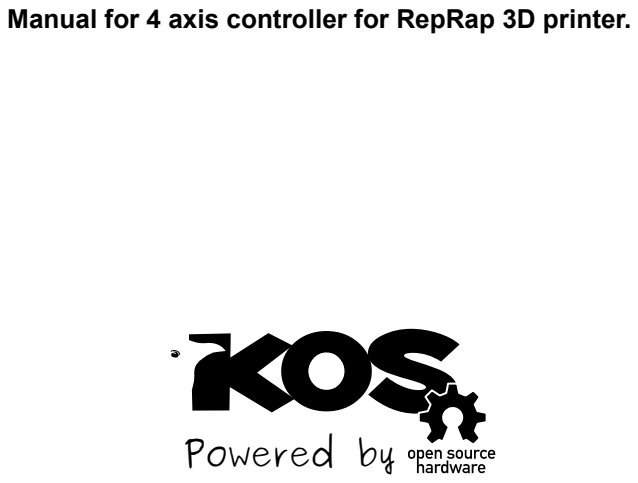
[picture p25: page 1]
Powered by

## Contents

## 1 Introduction

KOS 1.2 is electronics created with experience from building 3D Prusa printers in mind. It's equipped with screw terminals, widely used in industrial electronics, that eliminate popular problems like wrongly crimped plugs or low joints quality. KOS 1.2 driver has also possesses easily distinguishable connectors for LCD screen, SD-card reader and encoder. Thanks to this the control panel can be placed anywhere with ease. Additionally a potentiometer has been included that serves for screen's contrast regulation and a resistor for brightness regulation.

One undeniable quality of KOS electronics is the possibility of using 3 different power sources at once. It means that we can power motors from Vmot with 12-30V, heaters from Vhot 12-30V and logics from P1 = 12V or directlyfrom the USB port. Not everyone needs such a diverse range of possibilities thus jumpers have been added to make the installation process easier.

KOS 1.2 electronics features an AT90USB1286/7 processor - an 8-bit controller widely used in RepRap-type 3D printers. One of it's qualities is compatibility with USB port, allowing for quick data exchange between your computer and the printer. This processor is used in electronics like Teensylu, Printboard, SAV MKI, Sunbeam, Uniqueone and many others. It's the most popular processor from AVR family in the world of 3D printing.

## 2 Assembly diagram

A diagram below depictures assembly of basic elements of the priter such as:

a heater, a heatbed, engines etc. It's vital that cables of right diameter are used.

- Engines: 0.35mm²
- Heaters: 1.5mm²
- Limits, termistors, safety switch E-Stop: 0.35mm²
- Power supplies: 1.5mm²

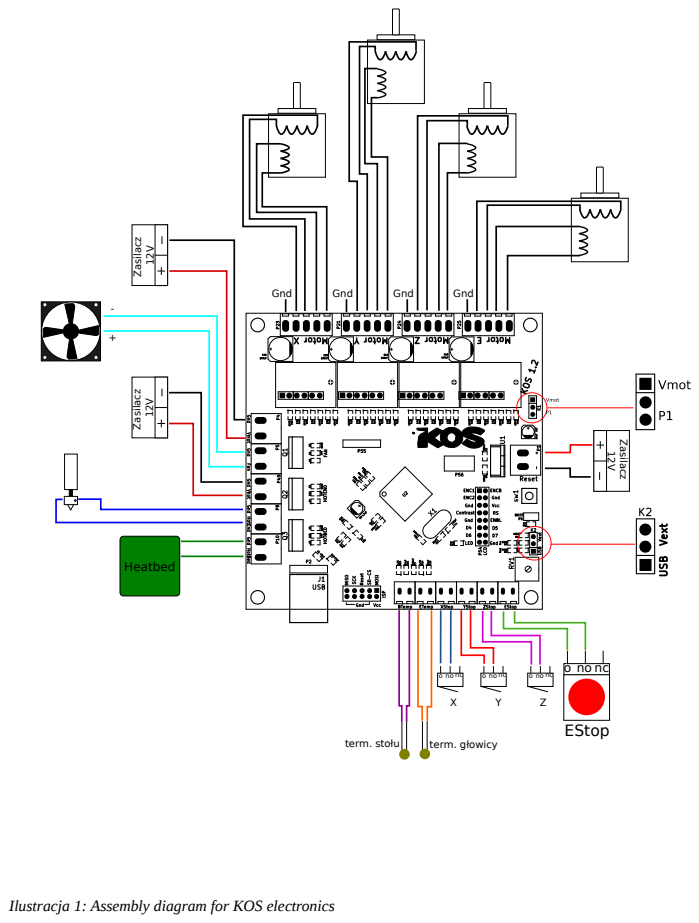
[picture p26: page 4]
Heatbed; term. stołu; term. głowicy; EStop; Zasilacz; Gnd

Ilustracja 1: Assembly diagram for KOS electronics

### 2.1 Description of jumpers responsible for choosing power source

KOS electronics features multiple power sources usage depending on application. To implement that function two goldpin arrays have been installed to allow switching between them.

nr | Jumper | Description
1 | | No power source has been chosen.
2 | | USB port chosen as power source. K1 array is being disregarded here.
3 | | Vmot chosen as power source.
4 | | P1 chosen as power source.

### 2.2 Description of jumpers responsible for step mode selection

Each engine has jumpers assigned to it responsible for step control on step engine drivers based on Allegro A4988 chipset. Possible configurations are listed below.

nr | Jumpers | Description
1 | | Full-step mode (1)
2 | | Half-step mode (½)
3 | | Quarter-step mode (¼)
4 | | One-eigth-step mode (1/8)
5 | | One-sixteenth-step mode (1/16)

## 3 Windows drivers and software

KOS electronics is designed to be reversely compatibile with teensylu electronics so for it to work properly drivers' installation is required. If the electronics has Marlin pre-intalled then only teensy project's drivers are to be installed 1.

If that's not the casewe have to create a new compilation of Marlin. It's how-to is described in „Marlin Compilation” chapter 5. Before thet, however, our electronics requies libraries from Arduino, Teensyduino and FLIP that we have to install:

- Arduino's main page 2
- Teensyduino's main page 3
- FLIP for Windows 4

### 3.1 Arduino installation


Ilustracja 2: Allow the system to run the file

Ilustracja 3: Agree to the license agreement

Ilustracja 4: Pick components to be installed

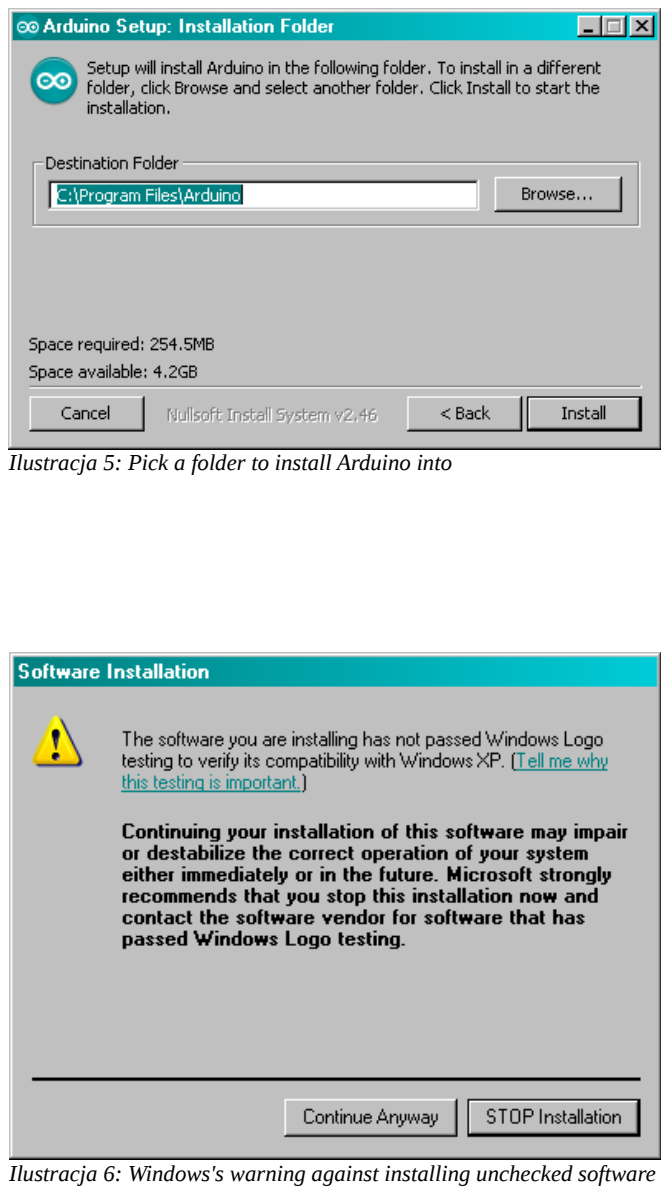
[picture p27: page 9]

Ilustracja 5: Pick a folder to install Arduino into

Ilustracja 6: Windows's warning against installing unchecked software

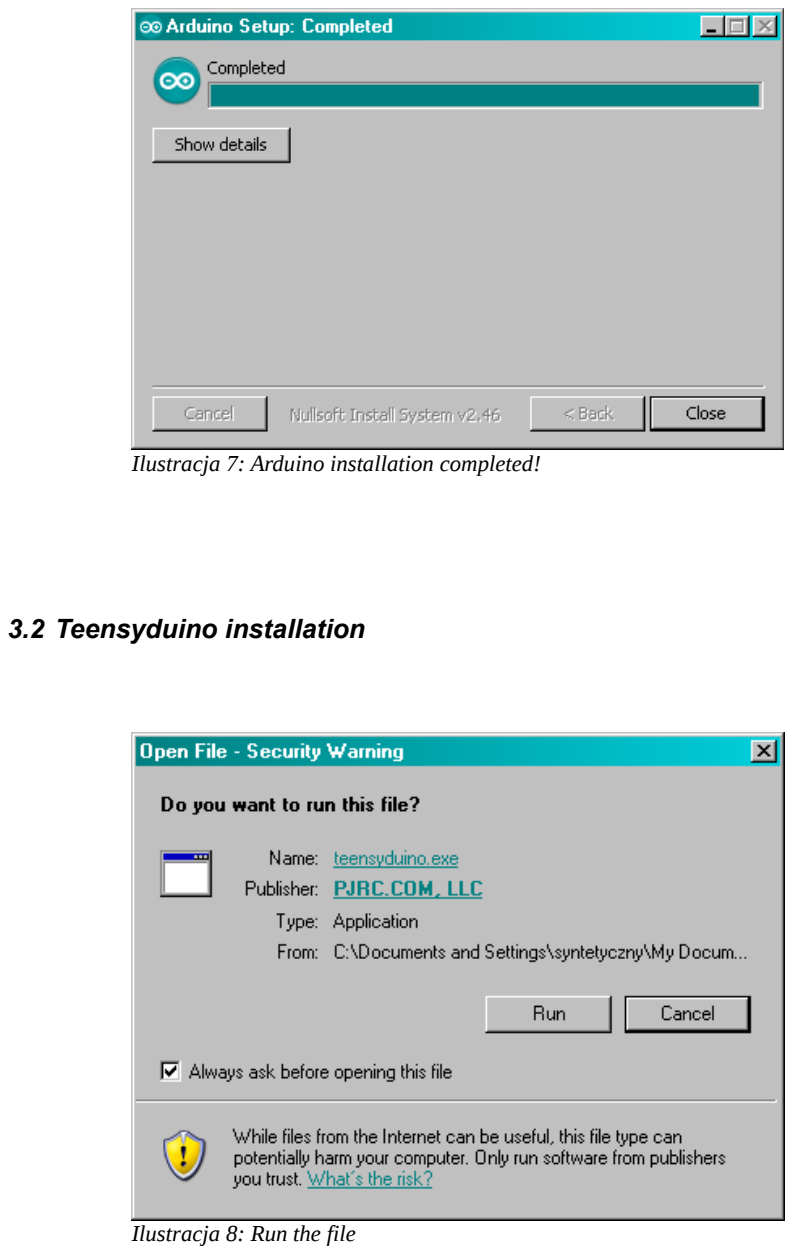
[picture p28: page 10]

### 3.2 Teensyduino installation

Ilustracja 8: Run the file

Ilustracja 7: Arduino installation completed!

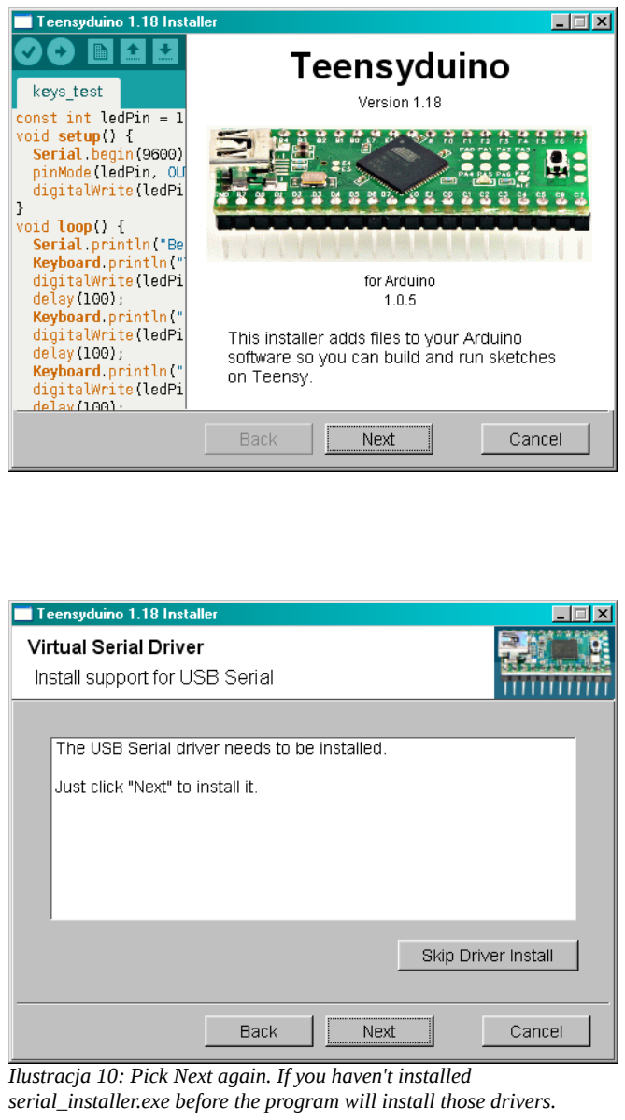
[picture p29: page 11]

Ilustracja 10: Pick Next again. If you haven't installed serial_installer.exe before the program will install those drivers.

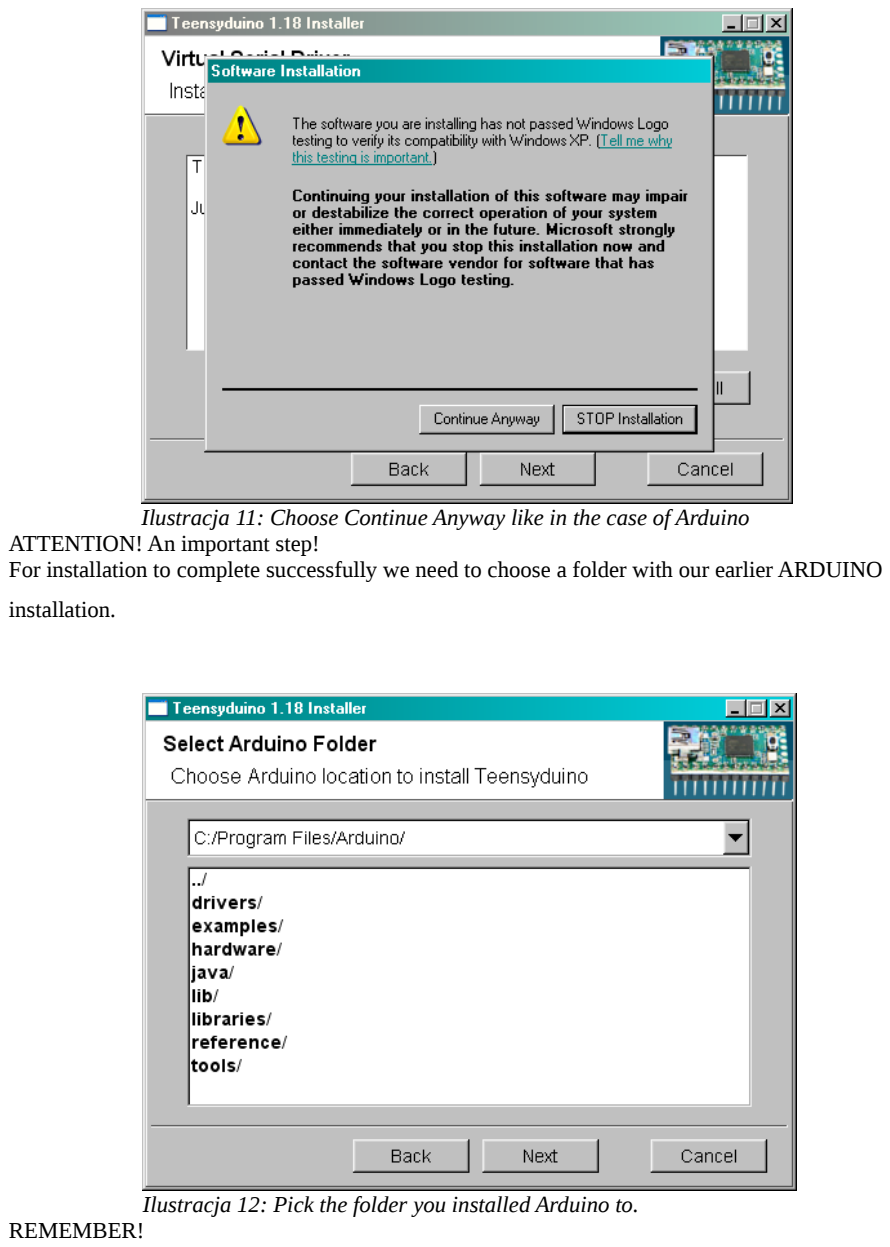
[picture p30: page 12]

ATTENTION! An important step!
For installation to complete successfully we need to choose a folder with our earlier ARDUINO installation.

REMEMBER!

Ilustracja 11: Choose Continue Anyway like in the case of Arduino

Ilustracja 12: Pick the folder you installed Arduino to.

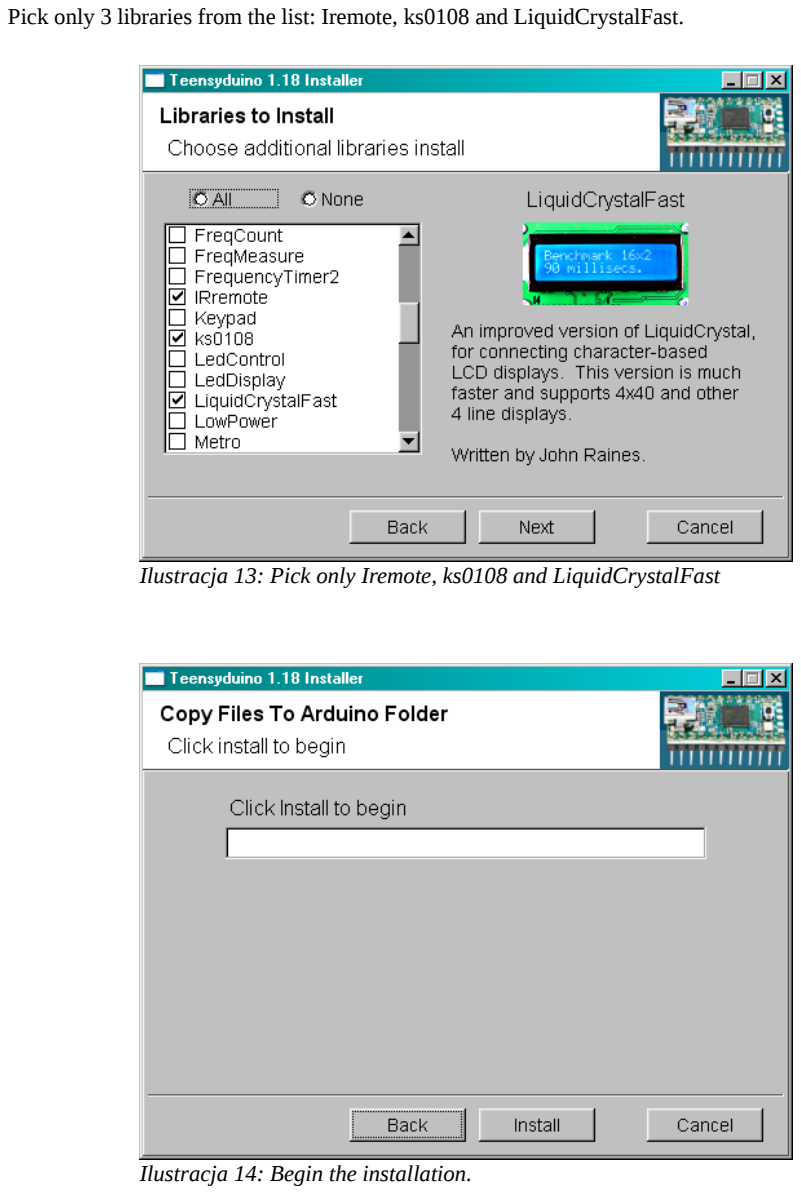
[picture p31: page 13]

Pick only 3 libraries from the list: Iremote, ks0108 and LiquidCrystalFast.

Ilustracja 13: Pick only Iremote, ks0108 and LiquidCrystalFast

Ilustracja 14: Begin the installation.

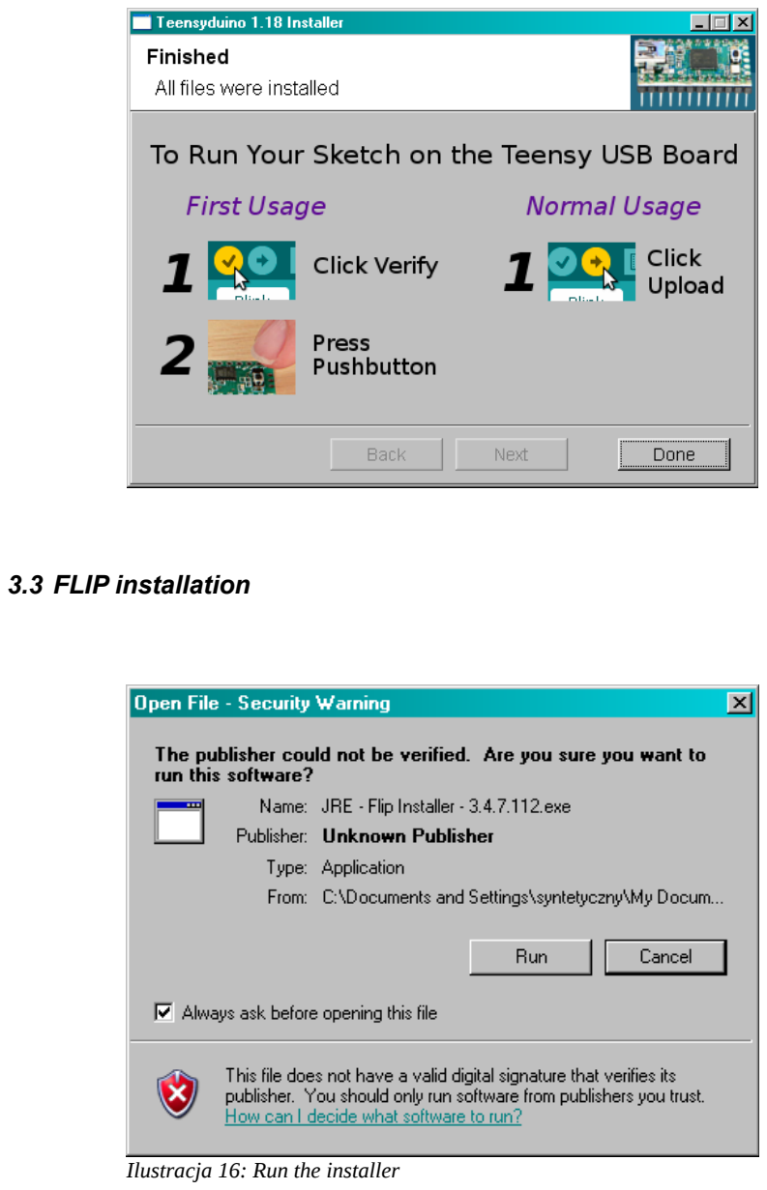
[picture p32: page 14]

### 3.3 FLIP installation

Ilustracja 16: Run the installer

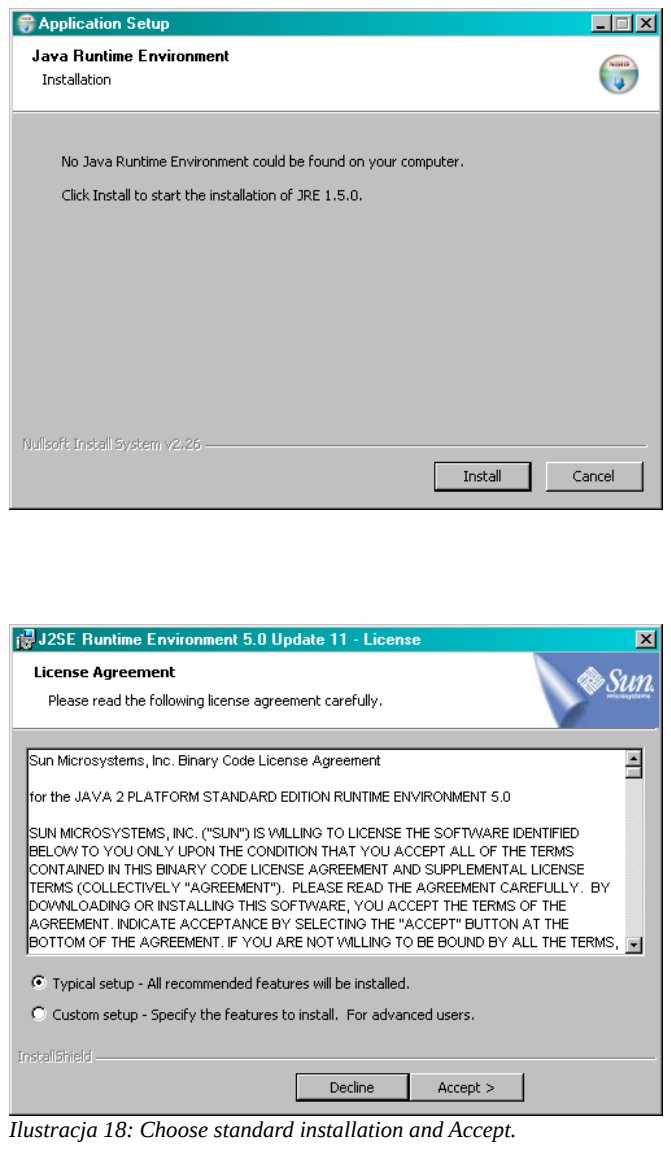
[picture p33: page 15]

Ilustracja 18: Choose standard installation and Accept.

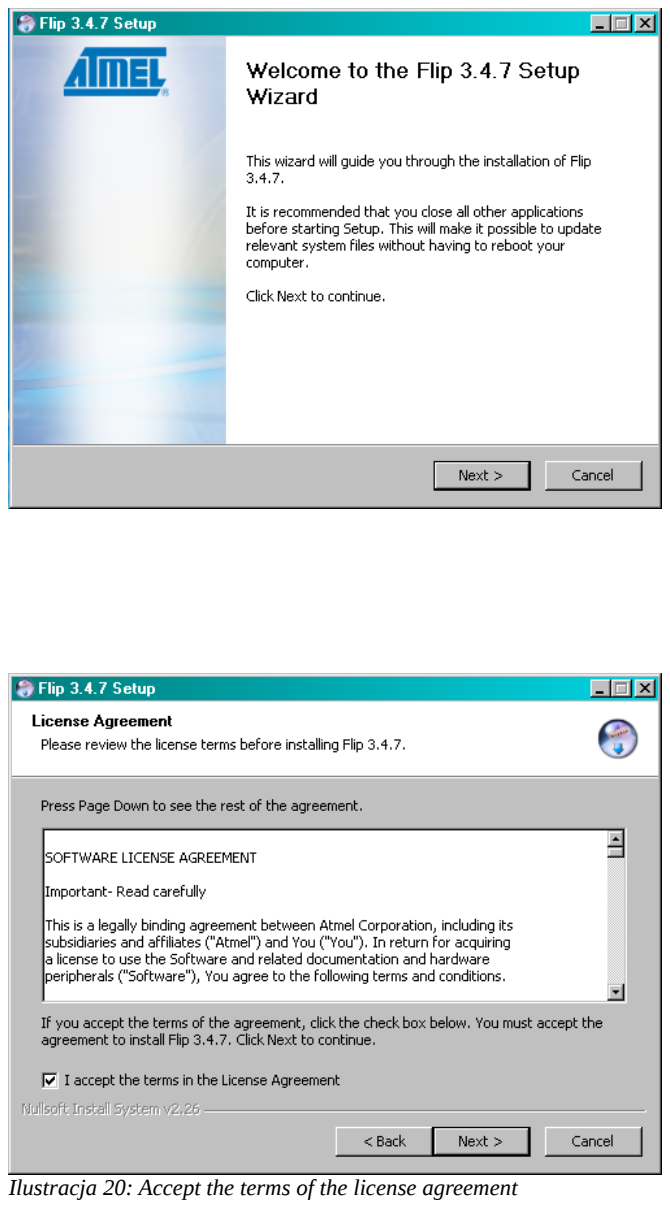
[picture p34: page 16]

Ilustracja 20: Accept the terms of the license agreement

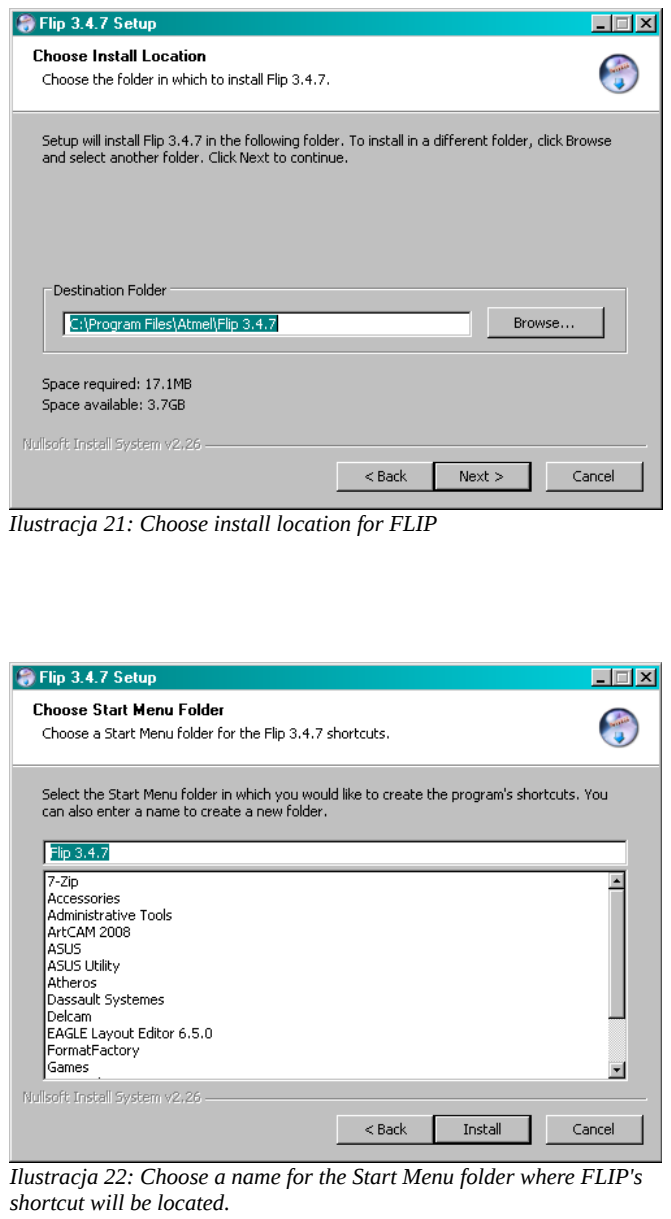
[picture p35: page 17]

Ilustracja 21: Choose install location for FLIP

Ilustracja 22: Choose a name for the Start Menu folder where FLIP's shortcut will be located.

Ilustracja 24: Choose if you want to have a desktop shortcut created and if you want to open the Readme file.

## 4 Linux Ubuntu drivers and software

Begin with downloading Arduino drivers from their main page 2 . After you finish unpacking drivers open a terminal (Ctrl + Alt + T) and install necessary files :

sudo apt-get install gcc-avr avr-libc

sudo apt-get install openjdk-6-jre

Next, we add execution rights for Arduino. To do that we have to open the Arduino installation folder and click the file with right mouse button opening Properties and in Rights tab choose Allow to execute file.

Next step is downloading teensyduino from it's homepage in a version for our operating system (32/64 bits) and saving it in a location of our choice. To execute the program we need to open the terminal (Ctrl + Alt + t) and select a location of the file:

cd /home/user_name/Location/File

Next by using the chmod command we add execution rights to teensyduino.32bit

chmod 755 teensyduino.32bit

Then open the installer with ./teensyduino.32bit command and follow the instructions:

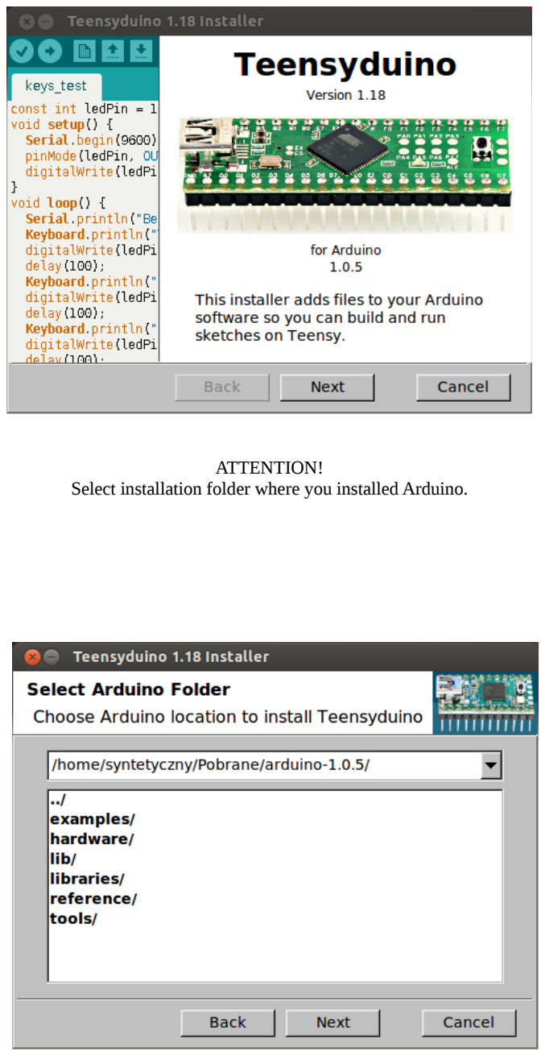
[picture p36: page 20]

ATTENTION!
Select installation folder where you installed Arduino.

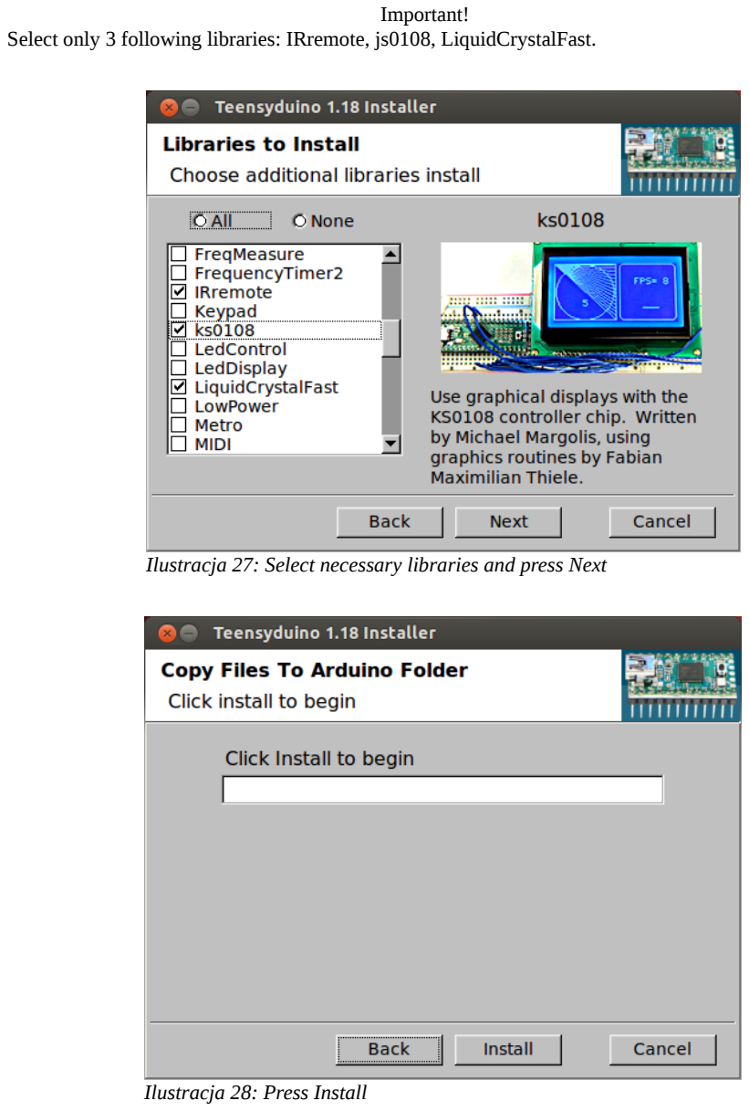
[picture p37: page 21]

Important!
Select only 3 following libraries: IRremote, js0108, LiquidCrystalFast.

Ilustracja 28: Press Install

Ilustracja 27: Select necessary libraries and press Next

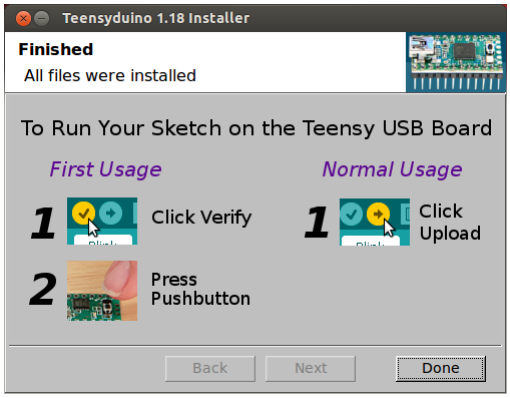
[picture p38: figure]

Next step we need to take is installation of equivalent of FLIP for AT90USB serier processors programming. Open the terminal and copy-paste following command:

sudo apt-get install dfu-programmer

The installer will download necessary application by itself and install the program on our computer. Thus finishing the installation of necessary drivers/libraries for Marlin.

## 5 Marlin compilation and installation on the KOS board

This chapter will focus on Marlin's compilation. That's because the installation differs slightly for different hardware configurations. Also this chapter will be divided into Ubuntu and Windows sections for the same reasons.

### 5.1 Marlin editing

Unpack files downloaded from Marlin's main page 5 to the folder you want Marlin installed to. Next by using any text-editing tool (e.x. Notepad++) open Configuration.h file and find the line : #define BAUDRATE 250000 and switch 250000 for 115000.

Now find the #define MOTHERBOARD 7 line and switch 7 for 8 thus changing the default configuration from ULTIMAKER to teensylu – one our driver is compatibile with (because of the same processor). Next step is choosing termistors we use. By default most heaters use EPCOS high-temperature termistors. Let's find a line that startslike this then:

#define TEMP_SENSOR_0 -1

#define TEMP_SENSOR_1 -1

#define TEMP_SENSOR_2 0

#define TEMP_SENSOR_BED 0

Each line defines one termistor and the last one defines the hotbed termistor. Values we have to set are 1 for TEMP_SENSOR_0 and TEMP_SENSOR_BED if we use a hotbed.

#define TEMP_SENSOR_0 1

#define TEMP_SENSOR_1 0

#define TEMP_SENSOR_2 0

#define TEMP_SENSOR_BED 1

This way we defined termistors used in our printer. Next we'll configure engines by setting custom number of steps per mm and the rotation's direction. The latter is defined by following lines:

#define INVERT_X_DIR true

#define INVERT_Y_DIR false

#define INVERT_Z_DIR true

#define INVERT_E0_DIR false

#define INVERT_E1_DIR false

#define INVERT_E2_DIR false

Each line defines spin in X,Y and Z axis and extruder's spin E0, E1 and E2. In most cases, however, only one extruder E0 is used.

true and false values describe the rotation's direction. Should the engines spin in the wrong direction just switch true for false and vice versa where necessary. To check if the extruder spins in the right direction just type in M302 command and press extrude to see if the extruder spins in the right direction.

Following line allows us to set a desired number of steps per mm.

#define DEFAULT_AXIS_STEPS_PER_UNIT {78.7402,78.7402,200.0*8/3,760*1.1}

The order of axes is as follows: X, Y, Z, E. The number of steps can be easily calculated using Josef Prusa's calculator 6 .

When the file is read we can open Arduino.

### 5.2 Marlin compilation

To open a Marlin project we need to click File→Open and choose the Marlin.ino file. The opened file is presented below. 30.

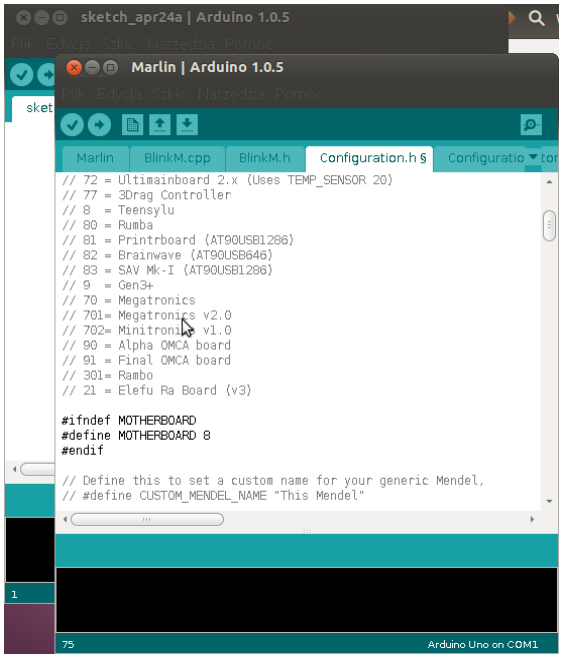
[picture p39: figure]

All configuration settings are stored in Configuration.h file. In Tools→ Board menu we have to pick Teensy2.0++ and compile the project by clicking the tick button in the top-left of the window (here marked yellow). 31.

After the compilation has finished a window should open with a Marlin.cpp.hex file 32.

Using the icon below the File menu or by going through File → Open Hex File we can choose Marlin.cpp.hex and move it to location of our choice 33.

Ilustracja 33: Store the Marlin.cpp.hex file in location of your preference

### 5.3 Marlin.cpp.hex installation on Windows

Installing the program on the driver requires Flip software. Before we open it, however, KOS electronics has to be plugged into your computer, BOOT jumper taken out and RESET button held for 5 seconds thus triggering programming mode. If it's the first time you do that then the system should notify you of new hardware. Driver's installation is similar to any other USB hardware. The only difference is that we have to manually

After the installation process completes open Flip.

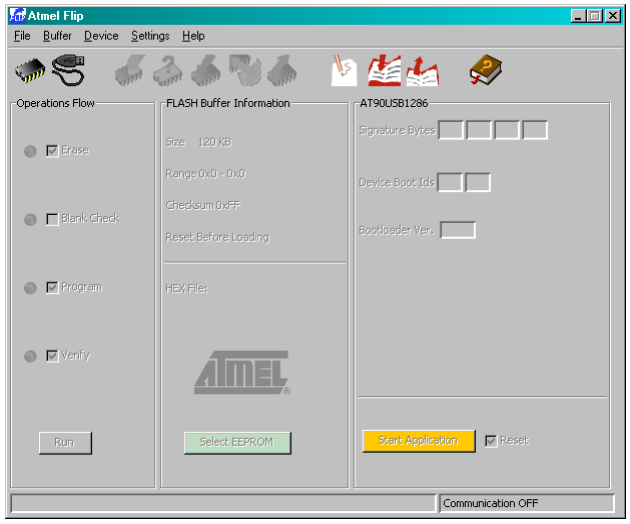
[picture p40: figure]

The software requires to be shown the processor to program. We can do that by pressing the first icon on the left.

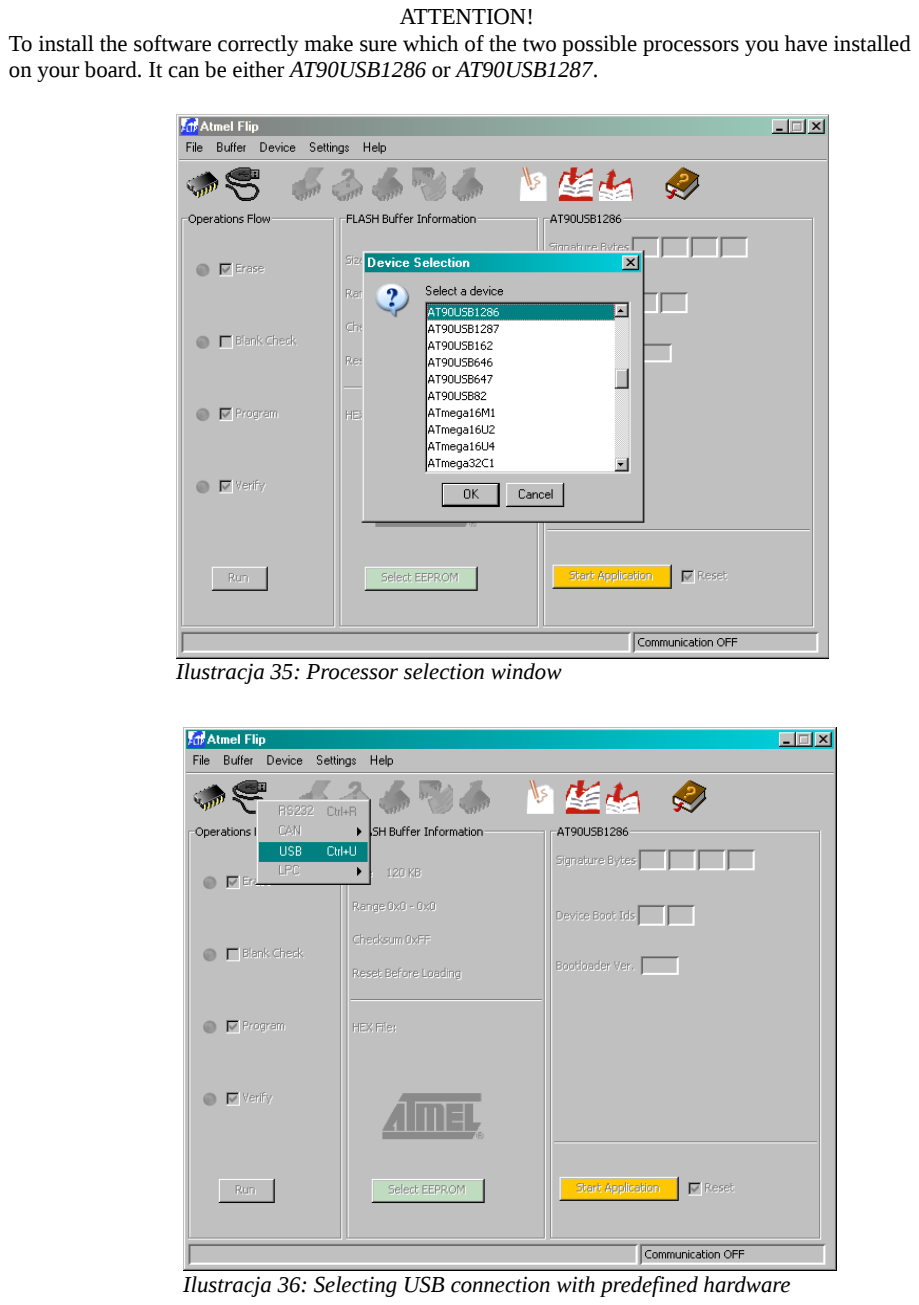
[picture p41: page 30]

ATTENTION!
To install the software correctly make sure which of the two possible processors you have installed on your board. It can be either AT90USB1286 or AT90USB1287.

Ilustracja 35: Processor selection window

Ilustracja 36: Selecting USB connection with predefined hardware

Next use the second icon from the left to establish connection.

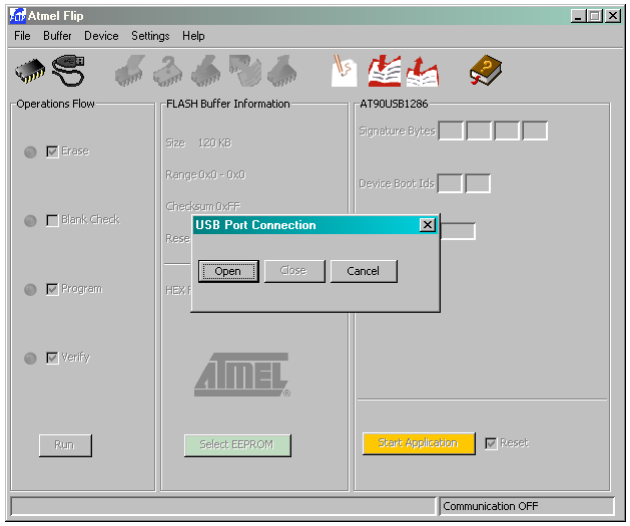
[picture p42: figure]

If the hardware has been installed correctly program should establish connection without a problem. Next select the order of operations you want to execute. In thiscase pick Erase and Program in the Operations Flow window.

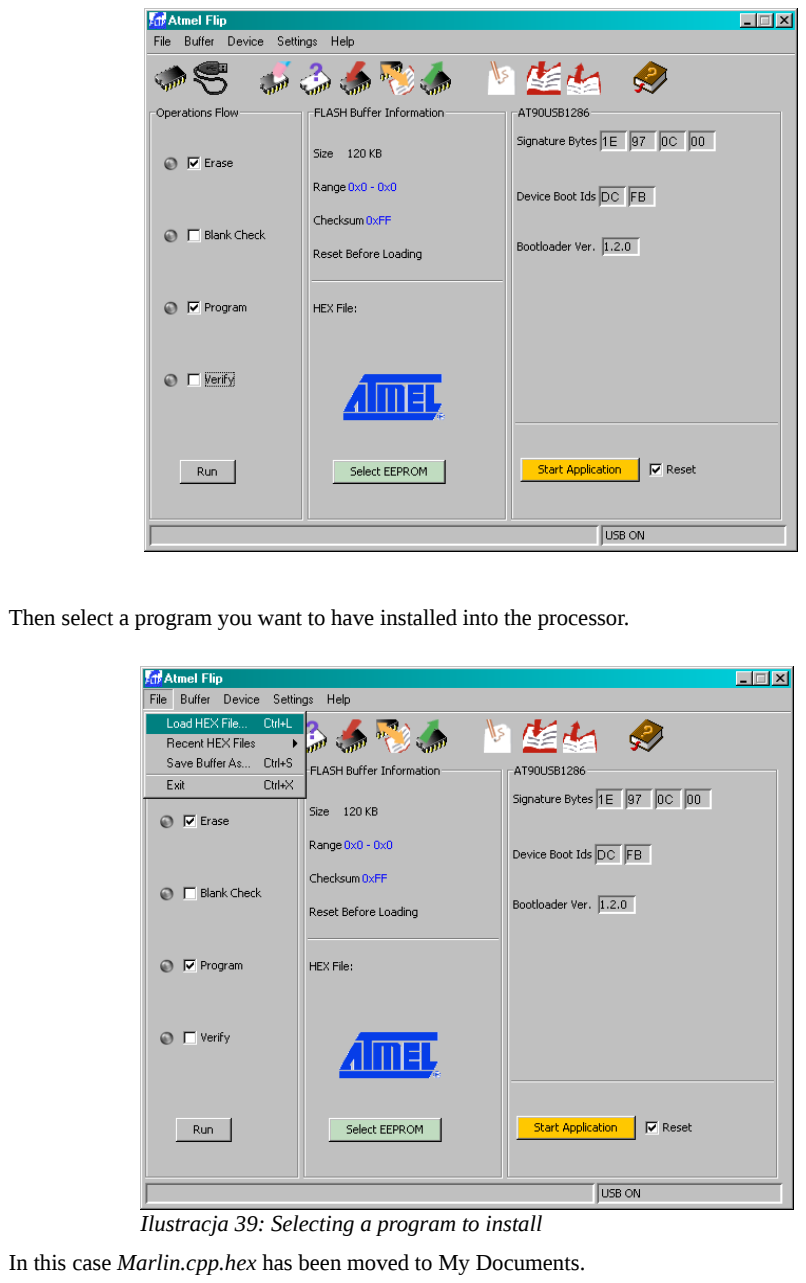
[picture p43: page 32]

Then select a program you want to have installed into the processor.

In this case Marlin.cpp.hex has been moved to My Documents.

Ilustracja 39: Selecting a program to install

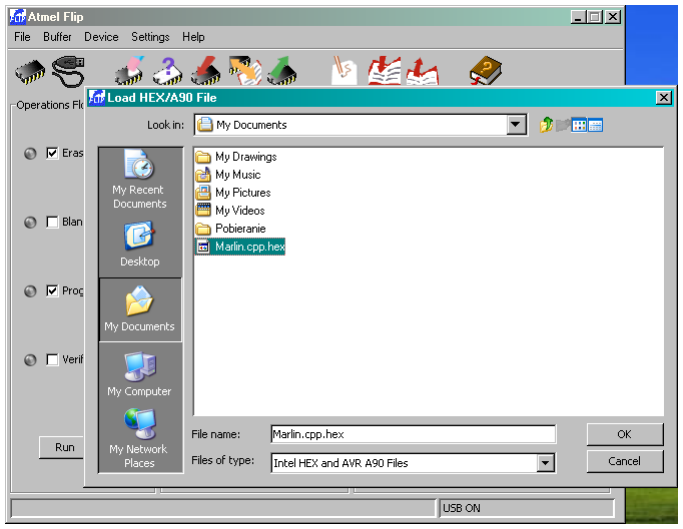
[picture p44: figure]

Ilustracja 40: Selecting your Marlin.cpp.hex file

After selecting right Marlin.cpp.hex file Flip window should look like this:

Click Run to start erasing and then programming the processor.

Ilustracja 42: Erasing processor's stored data.

Ilustracja 44: Success!

After putting BOOT jumper back in it's place and pressing RESET button once the driver should appear as a virtual port. This means the driver is ready to go.

### 5.4 Marlin.cpp.hex installation on Linux

To program KOS electronics driver first move Marlin.cpp.hex to main folder in your system /home/user_name/ 33. Next summon a terminal using ctrl + alt + t and make sure the file is in the main folder using the dir -l Marlin.cpp.hex command.

Being sure you're in the right directory plug in the KOS controller using USB cable. Pull out the BOOT jumper and hold RESET button for 5 seconds to trigger programming mode. Using lsusb command check if the programming mode has been triggered.

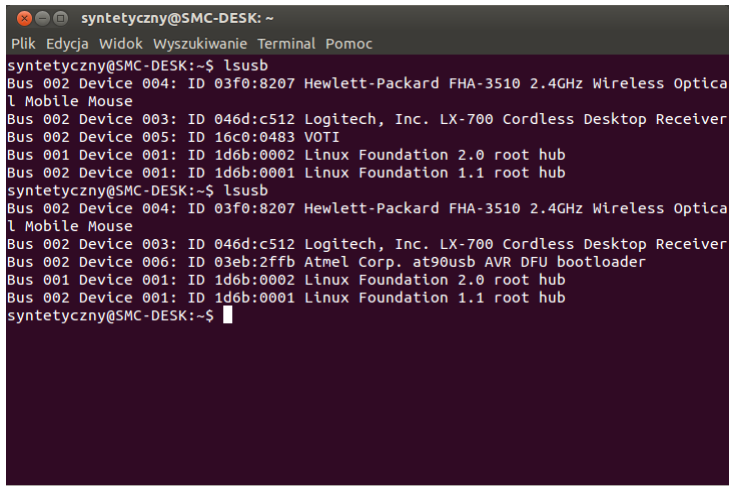
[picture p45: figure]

Next by using dfu-programmer installed earlier clean the processor's memory and install the program into the processor.

ATTENTION!
To successfully install the software make check which of two possible processors you have installed

Ilustracja 45: Checking if the driver is in programming mode – it'll switch from VOTI response to Atmel Corp. at90usb on the board. It can be either AT90USB1286 or AT90USB1287. When you make sure use the following commands:

sudo dfu-programmer at90usb1286 erase

sudo dfu-programmer at90usb1286 flash Marlin.cpp.hex

(if your processor is AT90USB1287 switch 6 for 7 in both commands)

If everything goes well the outcome should look like this:

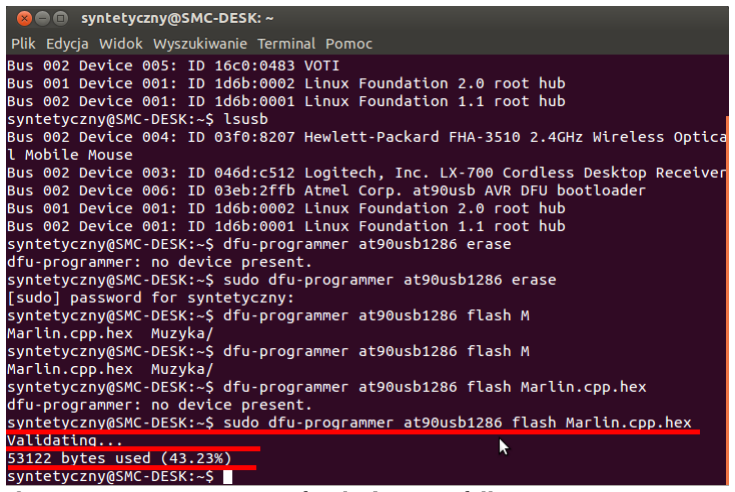
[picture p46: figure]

After placing BOOT jumper back in it's place and pressing the RESET button once the driver should respond as VOTI after using the lsusb command. If it does, then the installation has been successful and the driver is ready to go.

Ilustracja 46: Programming finished successfully.

## 6 Sources and additional info about KOS

Besides Marlin Repetier software can be used too. For this reason github repositories have been created with forks for this particular firmware which require only compilation for mechanical configuration that we desire. To download those just use the links provided below:

https://github.com/syntetyczny/Marlin/tree/Marlin_KOS

https://github.com/syntetyczny/Repetier-Firmware

There you can find preconfigured software for KOS electronics. Those configurations were created with SD cards, encoders and LCD screen in mind. Diagram below shows where those devices are to be plugged in.

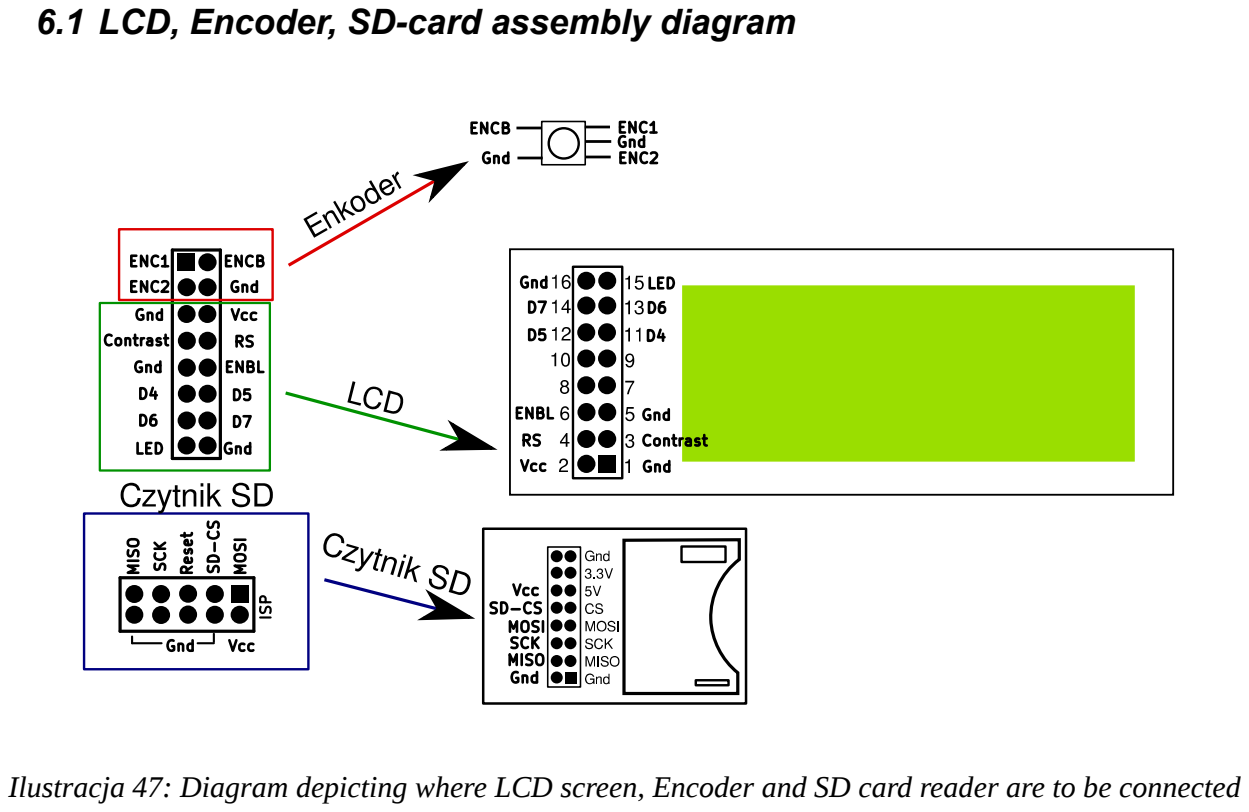
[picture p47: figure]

### 6.1 LCD, Encoder, SD-card assembly diagram

Ilustracja 47: Diagram depicting where LCD screen, Encoder and SD card reader are to be connected

## 7 Bibliography

1. serial_install.exe from 10.02.2014, www.pjrc.com/teensy/serial_install.exe
2. Arduino installer from 23.04.2014, http://arduino.cc/en/Main/Software
3. Teensyduino from 23.04.2014, http://www.pjrc.com/teensy/td_download.html
4. Flip for Windows from 23.04.2014, http://www.atmel.com/tools/flip.aspx
5. Marlin from 30.04.2014, https://github.com/ErikZalm/Marlin
6. Josef Prusa's calculator from 30.04.2014, http://calculator.josefprusa.cz

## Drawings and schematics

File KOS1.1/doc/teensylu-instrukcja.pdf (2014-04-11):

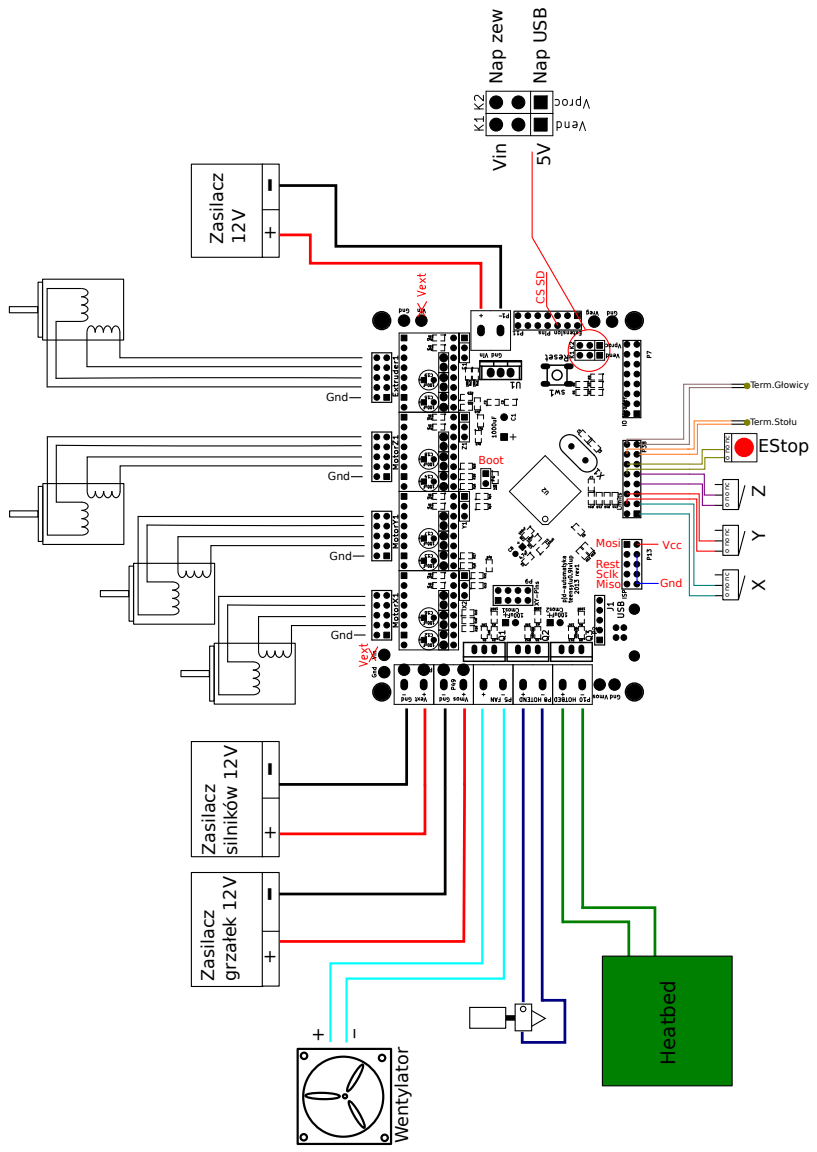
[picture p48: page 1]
Zasilacz; grzałek 12V; silników 12V + - + -; Heatbed; Term.Stołu; Term.Głowicy; Nap zew; Nap USB; Vin; Gnd; Mosi; Vcc; Rest Sclk Miso; Boot; EStop; Wentylator

## 1 Krańcówki

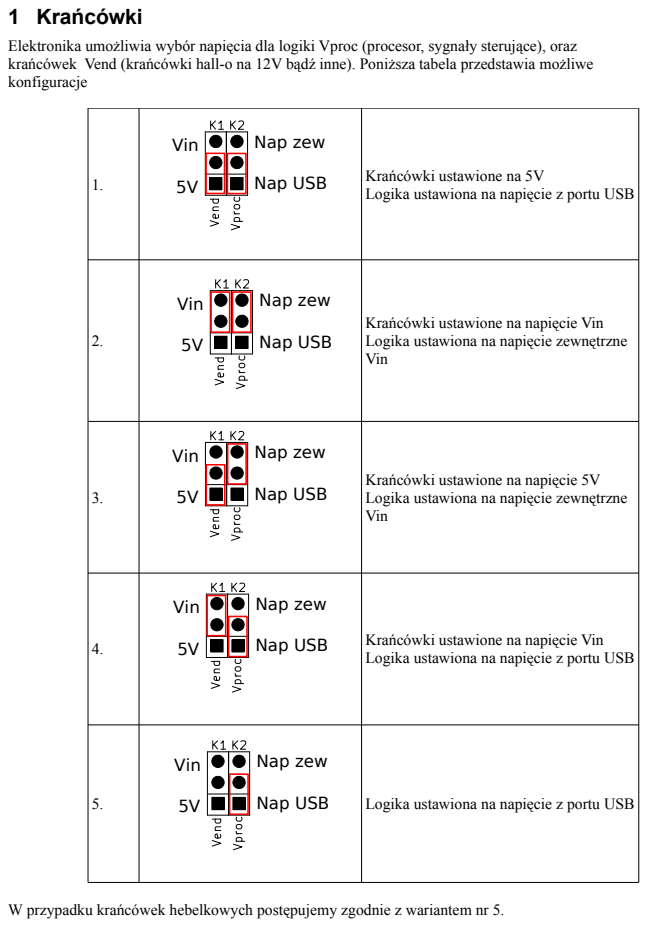
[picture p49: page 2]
Nap zew; Nap USB; Vin

Elektronika umożliwia wybór napięcia dla logiki Vproc (procesor, sygnały sterujące), oraz
krańcówek Vend (krańcówki hall-o na 12V bądź inne). Poniższa tabela przedstawia możliwe
konfiguracje

1. Krańcówki ustawione na 5V | Logika ustawiona na napięcie z portu USB

2. | Krańcówki ustawione na napięcie Vin Logika ustawiona na napięcie zewnętrzne Vin

3. | Krańcówki ustawione na napięcie 5V Logika ustawiona na napięcie zewnętrzne Vin

4. Krańcówki ustawione na napięcie Vin | Logika ustawiona na napięcie z portu USB

5. Logika ustawiona na napięcie z portu USB

W przypadku krańcówek hebelkowych postępujemy zgodnie z wariantem nr 5.

## 2 Stepstick

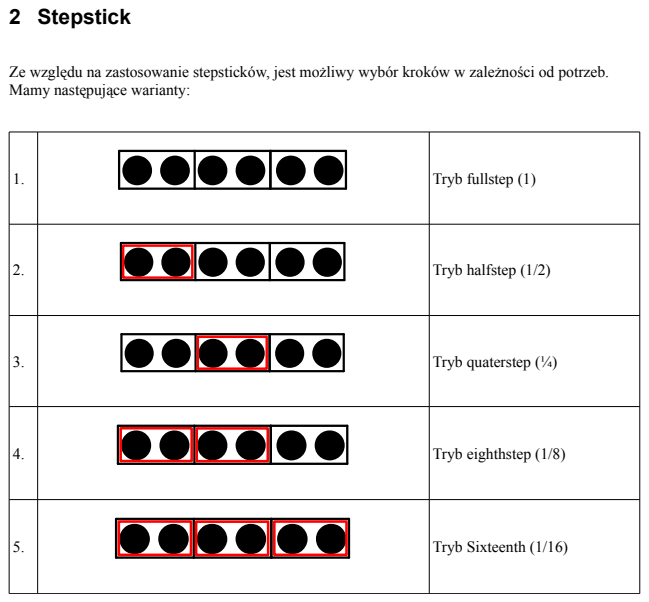
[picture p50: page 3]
1. Tryb fullstep (1); 2. Tryb halfstep (1/2); 3. Tryb quaterstep (¼); 4. Tryb eighthstep (1/8); 5. Tryb Sixteenth (1/16)

Ze względu na zastosowanie stepsticków, jest możliwy wybór kroków w zależności od potrzeb.
Mamy następujące warianty:

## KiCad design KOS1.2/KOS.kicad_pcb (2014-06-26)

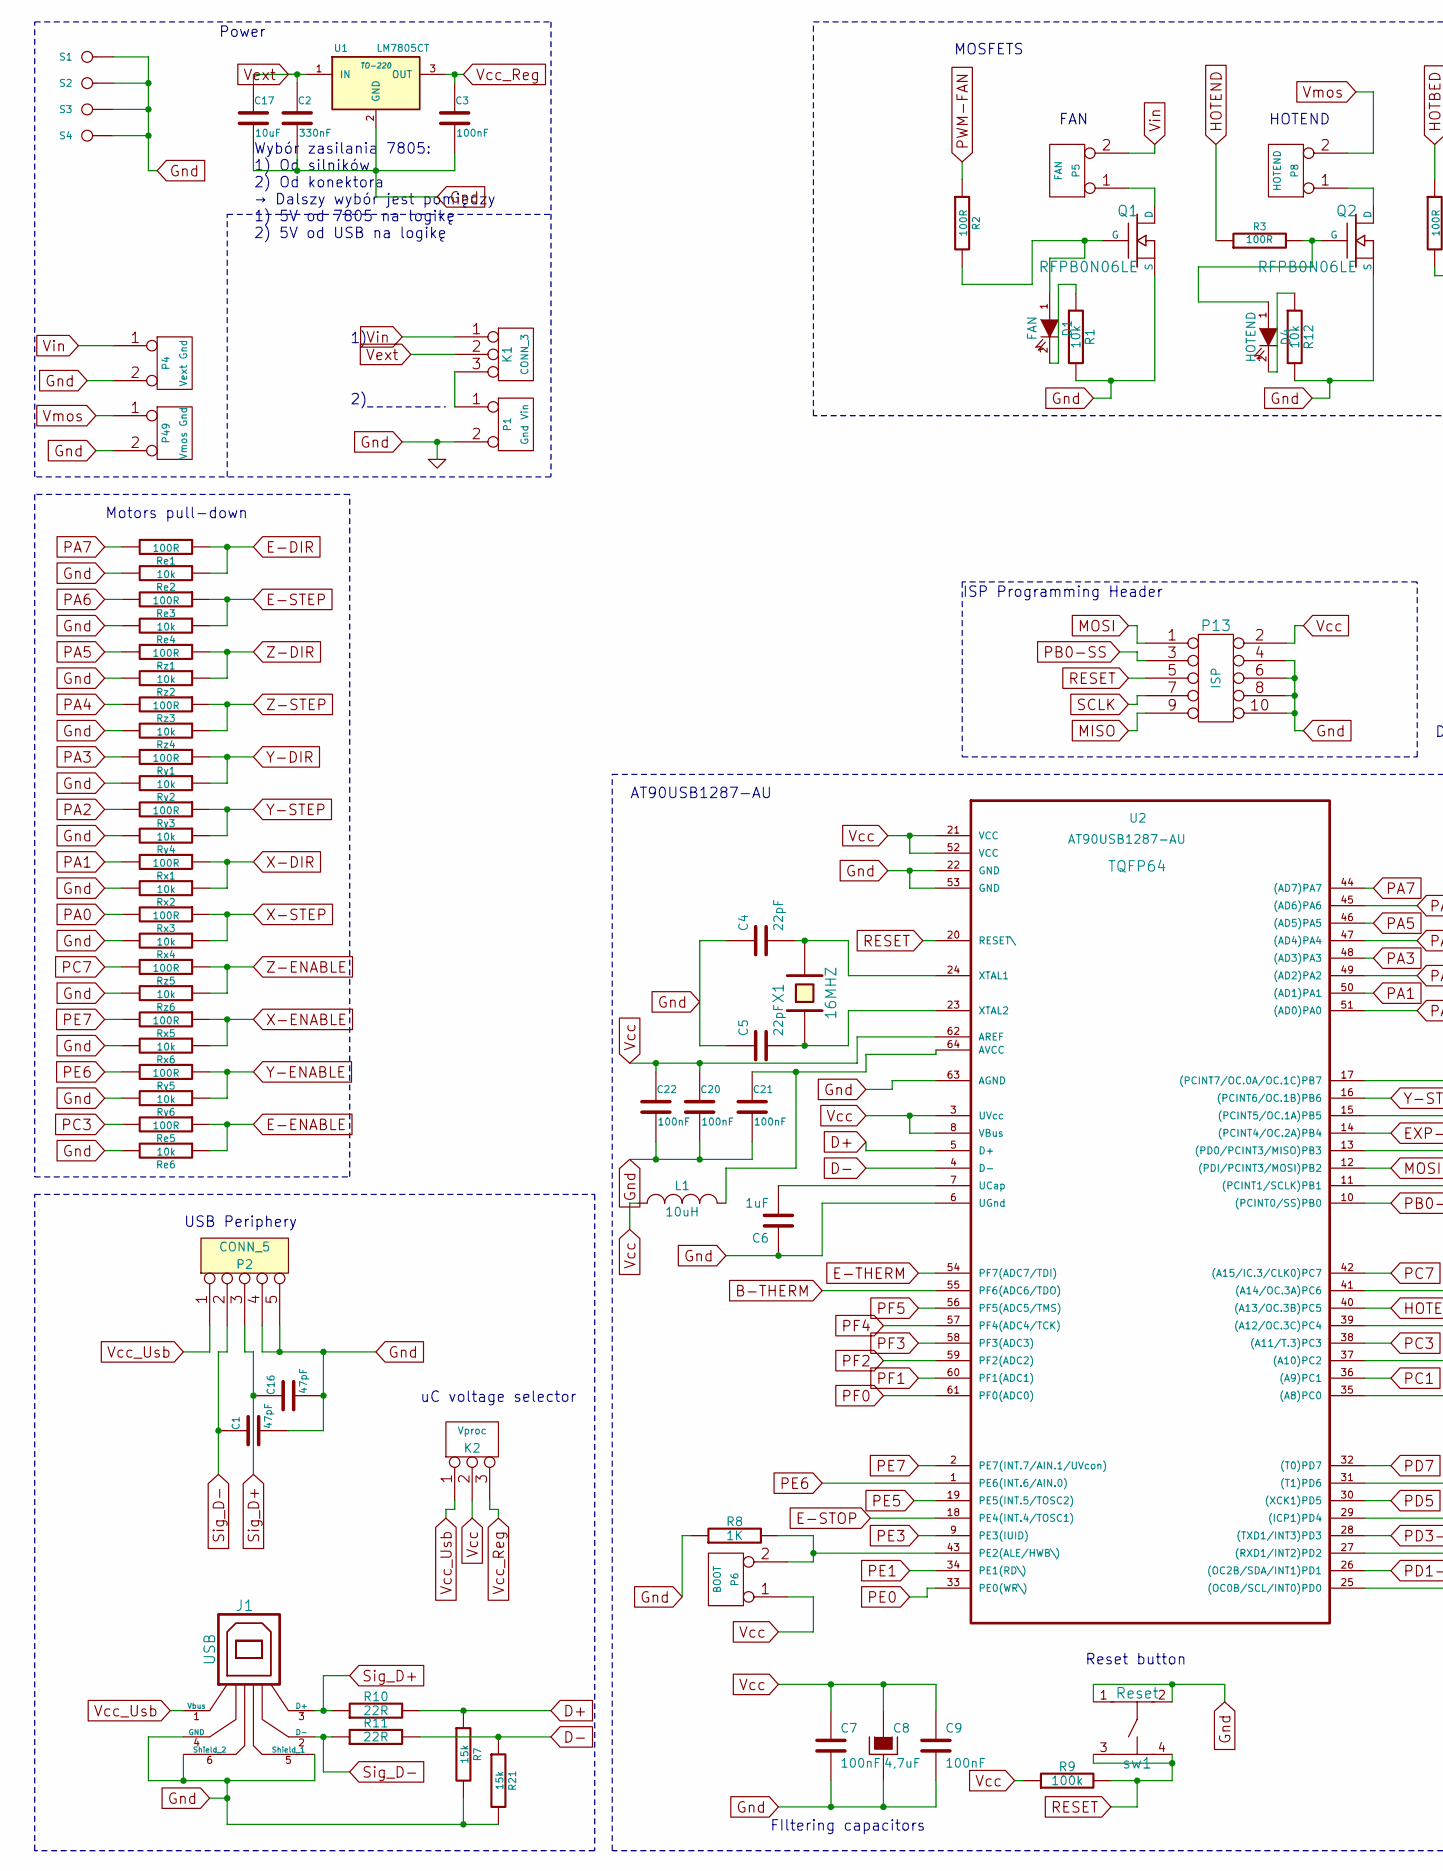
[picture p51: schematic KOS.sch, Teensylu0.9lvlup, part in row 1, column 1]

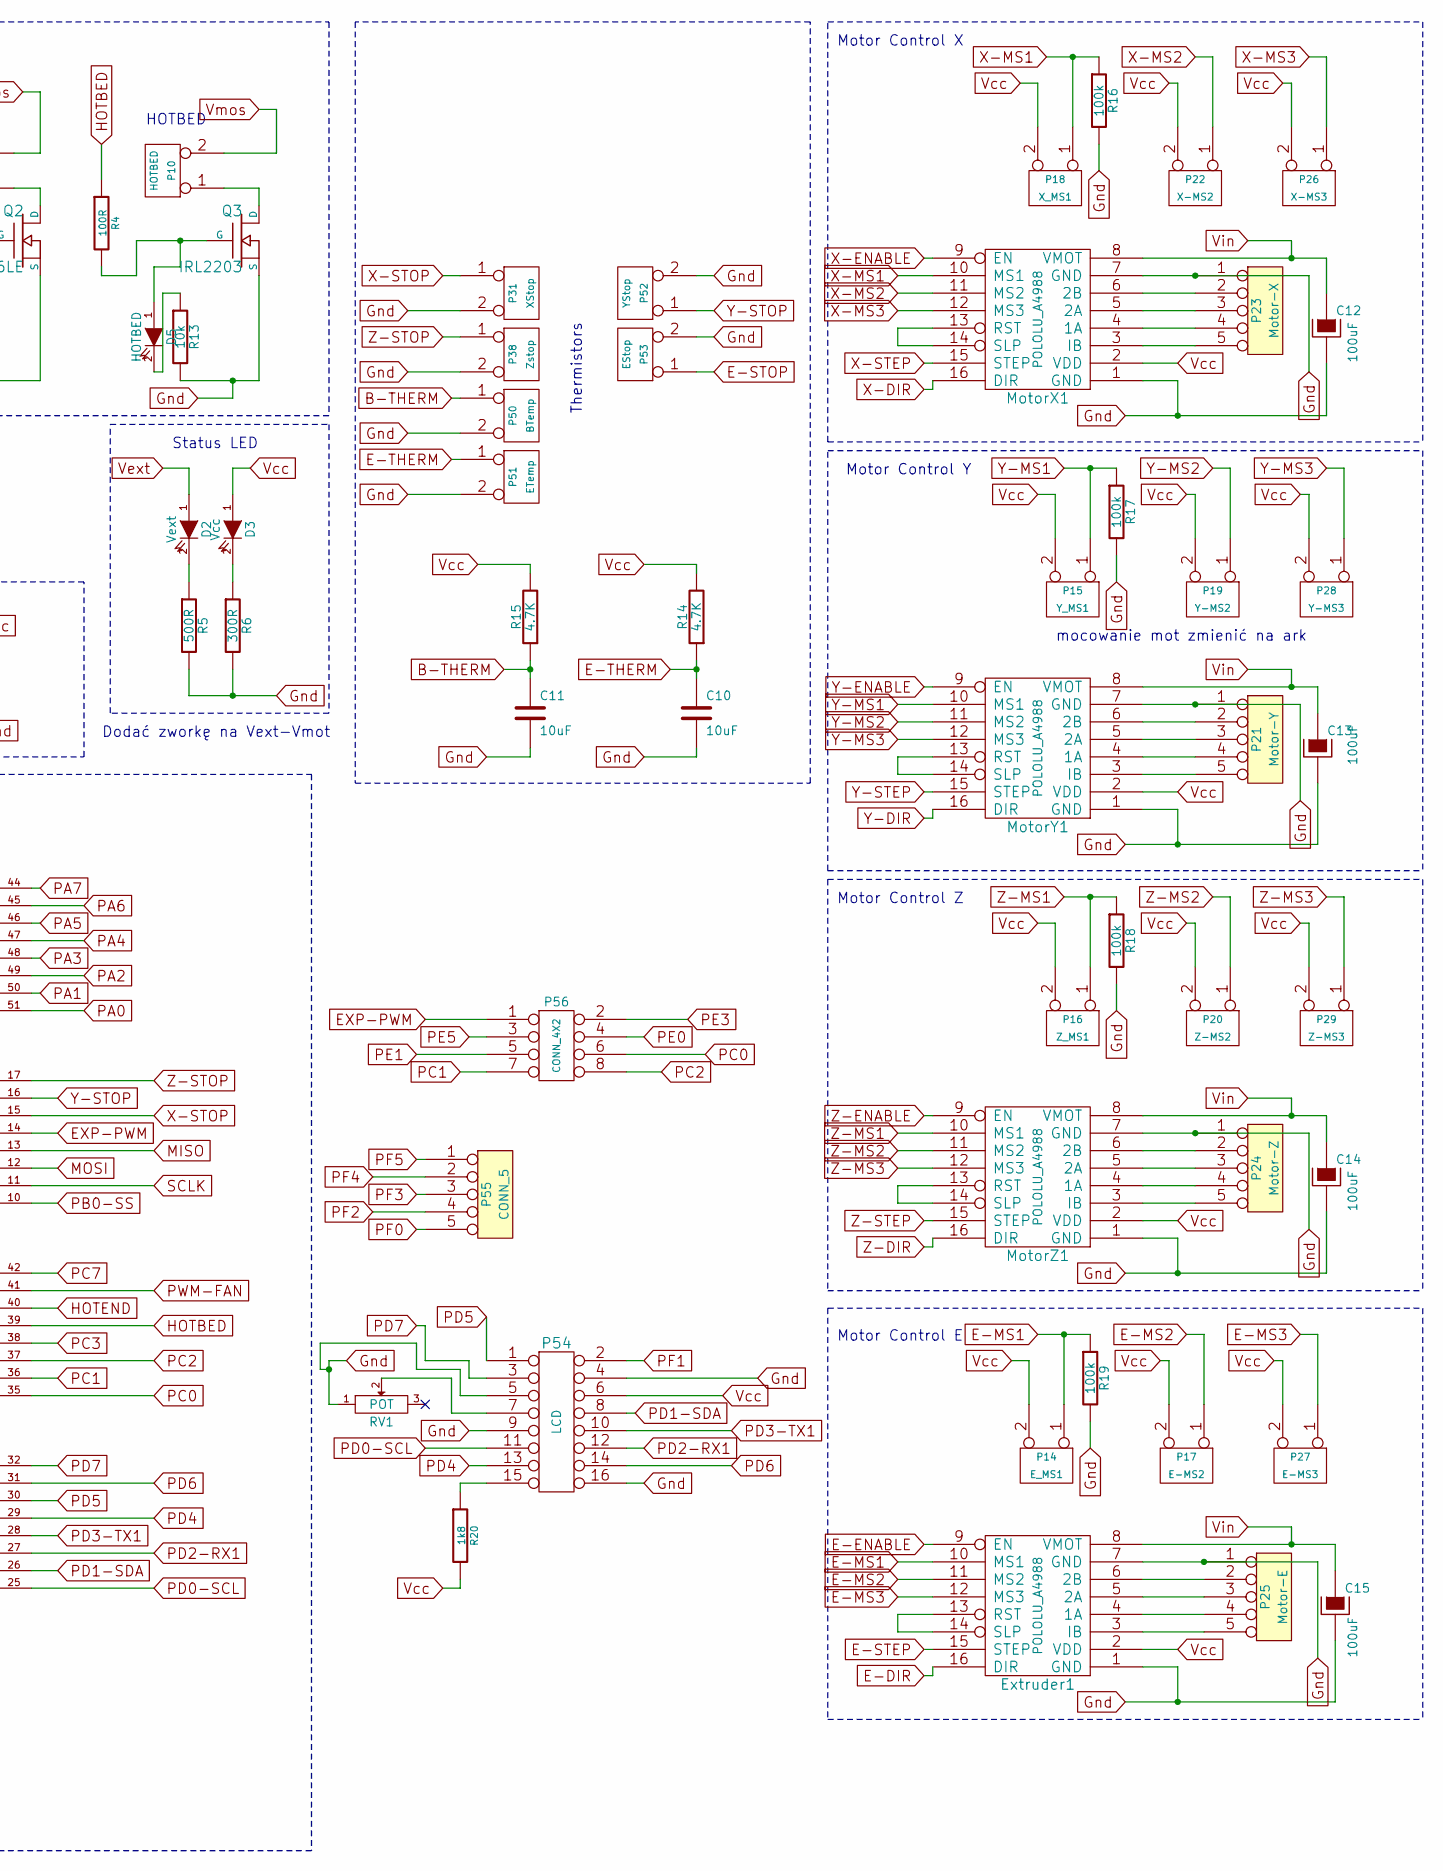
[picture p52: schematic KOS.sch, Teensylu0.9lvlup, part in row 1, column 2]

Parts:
C1, C16: 47pF
C2: 330nF
C3, C7, C9, C20, C21, C22: 100nF
C4, C5: 22pF
C6: 1uF
C8: 4,7uF
C10, C11, C17: 10uF
C12, C13, C14, C15: 100uF
D1: FAN
D2: Vext
D3: Vcc
D4: HOTEND
D5: HOTBED
Extruder1: POLOLU_A4988
J1: USB
K1: CONN_3
K2: Vproc
L1: 10uH
MotorX1: POLOLU_A4988
MotorY1: POLOLU_A4988
MotorZ1: POLOLU_A4988
P1: Gnd Vin
P2, P55: CONN_5
P4: Vext Gnd
P5: FAN
P6: BOOT
P8: HOTEND
P10: HOTBED
P13: ISP
P14: E_MS1
P15: Y_MS1
P16: Z_MS1
P17: E-MS2
P18: X_MS1
P19: Y-MS2
P20: Z-MS2
P21: Motor-Y
P22: X-MS2
P23: Motor-X
P24: Motor-Z
P25: Motor-E
P26: X-MS3
P27: E-MS3
P28: Y-MS3
P29: Z-MS3
P31: XStop
P38: Zstop
P49: Vmos Gnd
P50: BTemp
P51: ETemp
P52: YStop
P53: EStop
P54: LCD
P56: CONN_4X2
Q1, Q2: RFPB0N06LE
Q3: IRL2203
R1, R12, R13: 10k
R2, R3, R4: 100R
R5: 500R
R6: 300R
R7, R21: 15k
R8: 1K
R9, R16, R17, R18, R19: 100k
R10, R11: 22R
R14, R15: 4.7K
R20: 1k8
RV1: POT
Re1, Re3, Re5: 100R
Re2, Re4, Re6: 10k
Rx1, Rx3, Rx5: 100R
Rx2, Rx4, Rx6: 10k
Ry1, Ry3, Ry5: 100R
Ry2, Ry4, Ry6: 10k
Rz1, Rz3, Rz5: 100R
Rz2, Rz4, Rz6: 10k
S1, S2, S3, S4: S
U1: LM7805CT; TO-220
U2: AT90USB1287-AU
X1: 16MHZ
sw1: Reset

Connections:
B-THERM: C11.1, P50.1, R15.1, U2.55 (PF6(ADC6/TDO))
D+: R7.1, R10.2, U2.5 (D+)
D-: R11.2, R21.1, U2.4 (D-)
E-DIR: Extruder1.16 (DIR), Re1.1, Re2.1
E-ENABLE: Extruder1.9 (EN), Re5.1, Re6.1
E-MS1: Extruder1.10 (MS1), P14.1, R19.1
E-MS2: Extruder1.11 (MS2), P17.1
E-MS3: Extruder1.12 (MS3), P27.1
E-STEP: Extruder1.15 (STEP), Re3.1, Re4.1
E-STOP: P53.1, U2.18 (PE4(INT.4/TOSC1))
E-THERM: C10.1, P51.1, R14.1, U2.54 (PF7(ADC7/TDI))
EXP-PWM: P56.1, U2.14 ((PCINT4/OC.2A)PB4)
Gnd: C1.2, C2.2, C3.2, C4.1, C5.1, C6.1, C7.2, C8.2, C9.2, C10.2, C11.2, C12.2, C13.2, C14.2, C15.2, C16.2, C17.2, C20.2, C21.2, C22.2, Extruder1.1 (GND), Extruder1.7 (GND), J1.4 (GND), J1.5 (Shield_1), J1.6 (Shield_2), MotorX1.1 (GND), MotorX1.7 (GND), MotorY1.1 (GND), MotorY1.7 (GND), MotorZ1.1 (GND), MotorZ1.7 (GND), P1.2 (PM), P2.4, P2.5, P4.2 (PM), P13.4, P13.6, P13.8, P13.10, P21.1, P23.1, P24.1, P25.1, P31.2 (PM), P38.2 (PM), P49.2 (PM), P50.2 (PM), P51.2 (PM), P52.2 (PM), P53.2 (PM), P54.4, P54.5, P54.9, P54.16, Q1.S, Q2.S, Q3.S, R1.2, R5.2, R6.2, R7.2, R8.1, R12.2, R13.2, R16.2, R17.2, R18.2, R19.2, R21.2, RV1.1, Re2.2, Re4.2, Re6.2, Rx2.2, Rx4.2, Rx6.2, Ry2.2, Ry4.2, Ry6.2, Rz2.2, Rz4.2, Rz6.2, S1.1, S2.1, S3.1, S4.1, U1.2 (GND), U2.6 (UGnd), U2.22 (GND), U2.53 (GND), U2.63 (AGND), sw1.1, sw1.2
HOTBED: R4.1, U2.39 ((A12/OC.3C)PC4)
HOTEND: R3.1, U2.40 ((A13/OC.3B)PC5)
MISO: P13.9, U2.13 ((PD0/PCINT3/MISO)PB3)
MOSI: P13.1, U2.12 ((PDI/PCINT3/MOSI)PB2)
unnamed: Extruder1.13 (RST), Extruder1.14 (SLP)
unnamed: MotorY1.13 (RST), MotorY1.14 (SLP)
unnamed: MotorZ1.13 (RST), MotorZ1.14 (SLP)
unnamed: D4.2 (K), R12.1
unnamed: D5.2 (K), R13.1
unnamed: D5.1 (A), Q3.G, R4.2
unnamed: D1.2 (K), R1.1
unnamed: C6.2, U2.7 (UCap)
unnamed: C21.1, L1.2, U2.64 (AVCC)
unnamed: MotorX1.13 (RST), MotorX1.14 (SLP)
unnamed: D3.2 (K), R6.1
unnamed: P10.1, Q3.D
unnamed: P5.1, Q1.D
unnamed: P8.1, Q2.D
unnamed: P6.2 (PM), R8.2, U2.43 (PE2(ALE/HWB\))
unnamed: P54.15, R20.1
unnamed: P54.7, RV1.2
unnamed: K1.3, P1.1
unnamed: MotorY1.4 (1A), P21.4
unnamed: Extruder1.6 (2B), P25.2
unnamed: MotorZ1.3 (IB), P24.5
unnamed: MotorZ1.4 (1A), P24.4
unnamed: MotorZ1.5 (2A), P24.3
unnamed: MotorZ1.6 (2B), P24.2
unnamed: MotorY1.3 (IB), P21.5
unnamed: Extruder1.5 (2A), P25.3
unnamed: MotorY1.5 (2A), P21.3
unnamed: MotorY1.6 (2B), P21.2
unnamed: Extruder1.3 (IB), P25.5
unnamed: Extruder1.4 (1A), P25.4
unnamed: D4.1 (A), Q2.G, R3.2
unnamed: D1.1 (A), Q1.G, R2.2
unnamed: MotorX1.3 (IB), P23.5
unnamed: MotorX1.4 (1A), P23.4
unnamed: MotorX1.5 (2A), P23.3
unnamed: MotorX1.6 (2B), P23.2
unnamed: D2.2 (K), R5.1
unnamed: C4.2, U2.24 (XTAL1), X1.2
unnamed: C5.2, U2.23 (XTAL2), X1.1
PA0: Rx3.2, U2.51 ((AD0)PA0)
PA1: Rx1.2, U2.50 ((AD1)PA1)
PA2: Ry3.2, U2.49 ((AD2)PA2)
PA3: Ry1.2, U2.48 ((AD3)PA3)
PA4: Rz3.2, U2.47 ((AD4)PA4)
PA5: Rz1.2, U2.46 ((AD5)PA5)
PA6: Re3.2, U2.45 ((AD6)PA6)
PA7: Re1.2, U2.44 ((AD7)PA7)
PB0-SS: P13.3, U2.10 ((PCINT0/SS)PB0)
PC0: P56.6, U2.35 ((A8)PC0)
PC1: P56.7, U2.36 ((A9)PC1)
PC2: P56.8, U2.37 ((A10)PC2)
PC3: Re5.2, U2.38 ((A11/T.3)PC3)
PC7: Rz5.2, U2.42 ((A15/IC.3/CLK0)PC7)
PD0-SCL: P54.11, U2.25 ((OC0B/SCL/INT0)PD0)
PD1-SDA: P54.8, U2.26 ((OC2B/SDA/INT1)PD1)
PD2-RX1: P54.12, U2.27 ((RXD1/INT2)PD2)
PD3-TX1: P54.10, U2.28 ((TXD1/INT3)PD3)
PD4: P54.13, U2.29 ((ICP1)PD4)
PD5: P54.1, U2.30 ((XCK1)PD5)
PD6: P54.14, U2.31 ((T1)PD6)
PD7: P54.3, U2.32 ((T0)PD7)
PE0: P56.4, U2.33 (PE0(WR\))
PE1: P56.5, U2.34 (PE1(RD\))
PE3: P56.2, U2.9 (PE3(IUID))
PE5: P56.3, U2.19 (PE5(INT.5/TOSC2))
PE6: Ry5.2, U2.1 (PE6(INT.6/AIN.0))
PE7: Rx5.2, U2.2 (PE7(INT.7/AIN.1/UVcon))
PF0: P55.5, U2.61 (PF0(ADC0))
PF1: P54.2, U2.60 (PF1(ADC1))
PF2: P55.4, U2.59 (PF2(ADC2))
PF3: P55.3, U2.58 (PF3(ADC3))
PF4: P55.2, U2.57 (PF4(ADC4/TCK))
PF5: P55.1, U2.56 (PF5(ADC5/TMS))
PWM-FAN: R2.1, U2.41 ((A14/OC.3A)PC6)
RESET: P13.5, R9.2, U2.20 (RESET\), sw1.3, sw1.4
SCLK: P13.7, U2.11 ((PCINT1/SCLK)PB1)
Sig_D+: C16.1, J1.3 (D+), P2.3, R10.1
Sig_D-: C1.1, J1.2 (D-), P2.2, R11.1
Vcc: C7.1, C8.1, C9.1, C20.1, C22.1, D3.1 (A), Extruder1.2 (VDD), K2.2 (PM), L1.1, MotorX1.2 (VDD), MotorY1.2 (VDD), MotorZ1.2 (VDD), P6.1, P13.2, P14.2 (PM), P15.2 (PM), P16.2 (PM), P17.2 (PM), P18.2 (PM), P19.2 (PM), P20.2 (PM), P22.2 (PM), P26.2 (PM), P27.2 (PM), P28.2 (PM), P29.2 (PM), P54.6, R9.1, R14.2, R15.2, R20.2, U2.3 (UVcc), U2.8 (VBus), U2.21 (VCC), U2.52 (VCC), U2.62 (AREF)
Vcc_Reg: C3.1, K2.3, U1.3 (OUT)
Vcc_Usb: J1.1 (Vbus), K2.1, P2.1
Vext: C2.1, C17.1, D2.1 (A), K1.2 (PM), U1.1 (IN)
Vin: C12.1, C13.1, C14.1, C15.1, Extruder1.8 (VMOT), K1.1, MotorX1.8 (VMOT), MotorY1.8 (VMOT), MotorZ1.8 (VMOT), P4.1, P5.2 (PM)
Vmos: P8.2 (PM), P10.2 (PM), P49.1
X-DIR: MotorX1.16 (DIR), Rx1.1, Rx2.1
X-ENABLE: MotorX1.9 (EN), Rx5.1, Rx6.1
X-MS1: MotorX1.10 (MS1), P18.1, R16.1
X-MS2: MotorX1.11 (MS2), P22.1
X-MS3: MotorX1.12 (MS3), P26.1
X-STEP: MotorX1.15 (STEP), Rx3.1, Rx4.1
X-STOP: P31.1, U2.15 ((PCINT5/OC.1A)PB5)
Y-DIR: MotorY1.16 (DIR), Ry1.1, Ry2.1
Y-ENABLE: MotorY1.9 (EN), Ry5.1, Ry6.1
Y-MS1: MotorY1.10 (MS1), P15.1, R17.1
Y-MS2: MotorY1.11 (MS2), P19.1
Y-MS3: MotorY1.12 (MS3), P28.1
Y-STEP: MotorY1.15 (STEP), Ry3.1, Ry4.1
Y-STOP: P52.1, U2.16 ((PCINT6/OC.1B)PB6)
Z-DIR: MotorZ1.16 (DIR), Rz1.1, Rz2.1
Z-ENABLE: MotorZ1.9 (EN), Rz5.1, Rz6.1
Z-MS1: MotorZ1.10 (MS1), P16.1, R18.1
Z-MS2: MotorZ1.11 (MS2), P20.1
Z-MS3: MotorZ1.12 (MS3), P29.1
Z-STEP: MotorZ1.15 (STEP), Rz3.1, Rz4.1
Z-STOP: P38.1, U2.17 ((PCINT7/OC.0A/OC.1C)PB7)

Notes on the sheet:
Status LED
ISP Programming Header
MOSFETS
FIltering capacitors
Reset button
Motor Control Y
Motor Control Z
Motor Control E
Motor Control X
Thermistors
AT90USB1287-AU
FAN
HOTEND
HOTBED
USB Periphery
uC voltage selector
Motors pull-down
Power
mocowanie mot zmienić na ark
Dodać zworkę na Vext-Vmot
Wybór zasilania 7805: 1) Od silników 2) Od konektora → Dalszy wybór jest pomiędzy 1) 5V od 7805 na logikę 2) 5V od USB na logikę

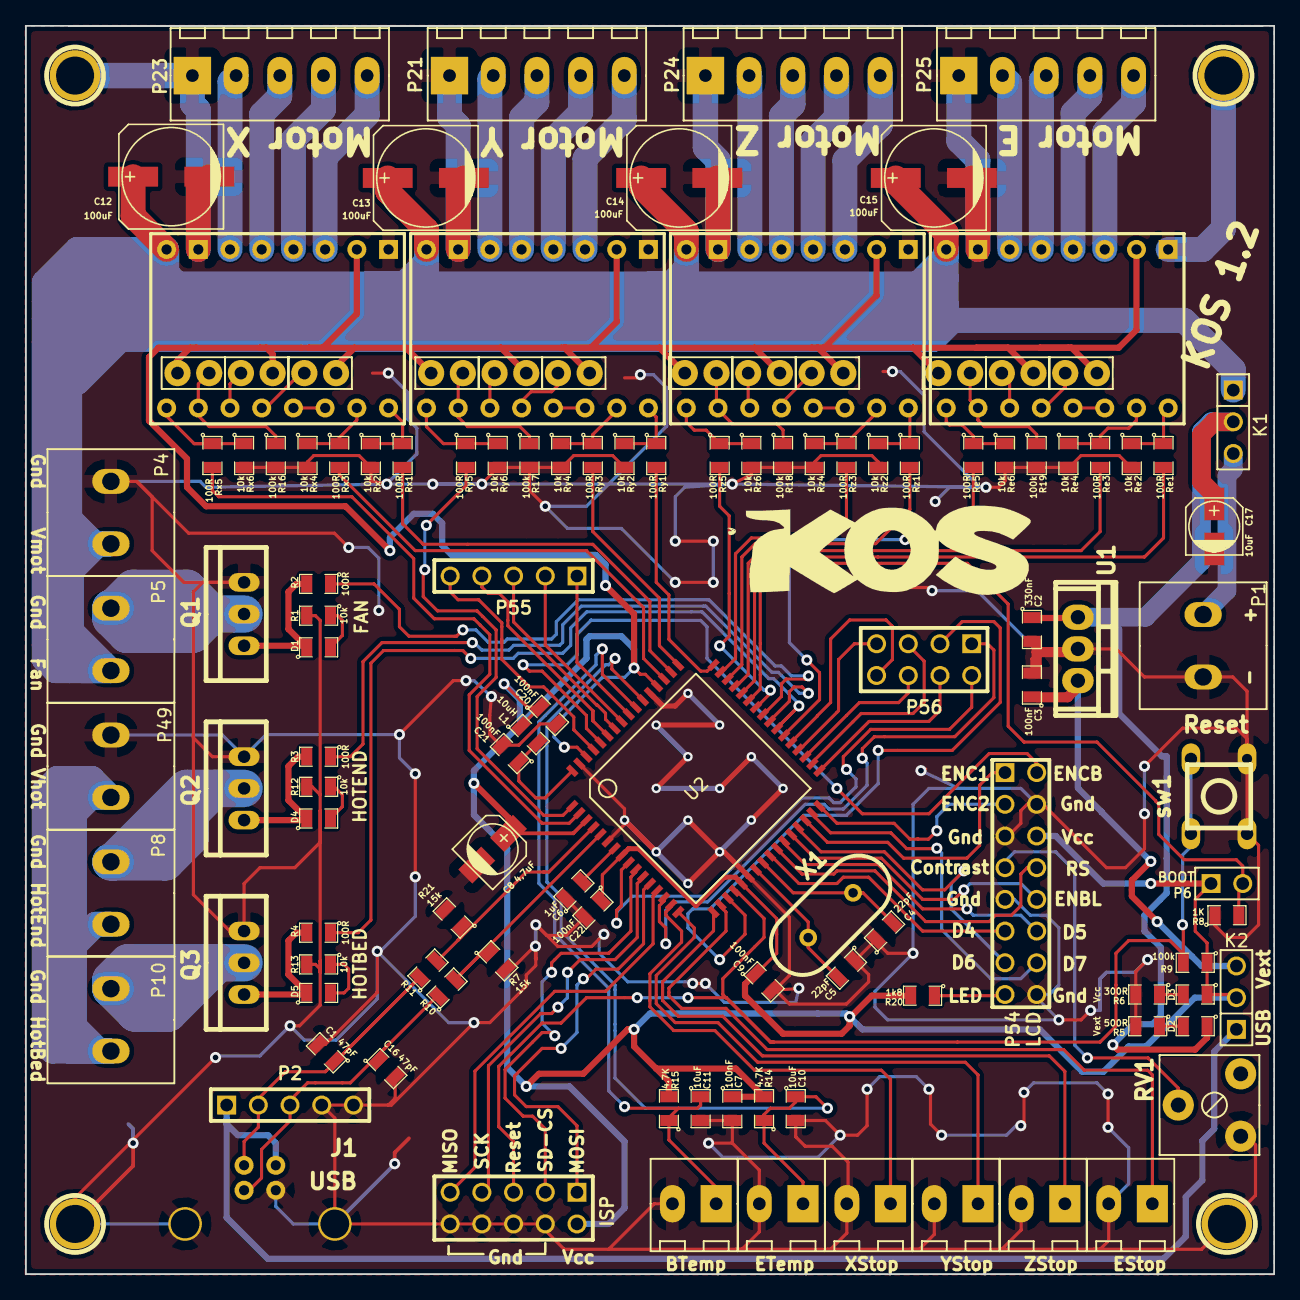
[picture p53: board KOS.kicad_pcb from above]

Board: 2 copper layers, 100.0 x 100.0 mm, 124 parts (0 on the bottom side), 122 nets.

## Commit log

2014-06-26 New version of KOS added with manuals
    [KOS-drl_map.dxf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]
2014-06-26 Remove gerb directory
    [KOS-drl_map.dxf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]
